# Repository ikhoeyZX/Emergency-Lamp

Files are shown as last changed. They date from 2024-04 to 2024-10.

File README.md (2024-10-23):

# Undens Lampu Emergency

This repository contains the source code for build a Emergency lamp based STM8 or ESP8266.

* Note: ESP8266 version are __not recommended__ but you can build it, but beware it sometimes crash and heating up when using step-up ic / module at low battery level (below 3V)

# Reason?

In my country there is much earthquake, well because i'm life in ring of fire area, i did experience big earthquake back in 2017. When earthquake happen, my family still sleeping (it around 12AM) and got blackout, there is no way to find door or find a place to protect our selfes because it's too dark to see. So that's why i make this in case it happen again we still got light to find exit or place to protect out selfes.

Most commercial emergency lamp in here are bad because cheap battery (only last 1 year and only hold 1.5h every running) and didn't have protection charger!!

# What version i should make?

There is 2 build exist (ESP8266 and STM8, arduino series will added later) for 1 layer recommended use v1.2 and for 2 layers smd build use v1.3

each folder contains how to build it. You need Android IDE to program it (in STM8 case, make sure your username in PC doesn't have "space" otherwise SDCPP will fail to build because this bug not yet fixed from SDCC it self).

* Note : For step-up ic/module you can find by self, depend of budget, because MOSFET output only act as "switch" so you need step-up to make sure it can output high voltage to light a leds (5v are common but waste much power, i recommended use 4.3v output to reduce power usage)
* MOSFET should be withstand around ~4A continues with heatsink, so if you using step-up and output set 4.3v it should be around ~4A Max in input side
* In my case only use 1A at MOSFET output and 4400mA battery. it can run without issue around 4H with 20 leds (~30mA/leds) in 12 places at home.

## Finished device:

| **Main device** | **A Step up ic MT3608** |
| :---: | :---: |
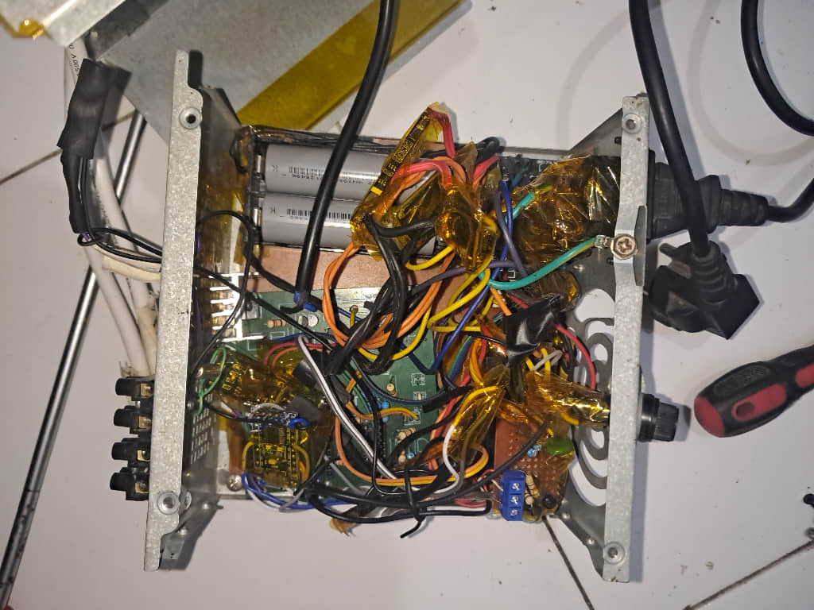
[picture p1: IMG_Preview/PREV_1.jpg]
Main device
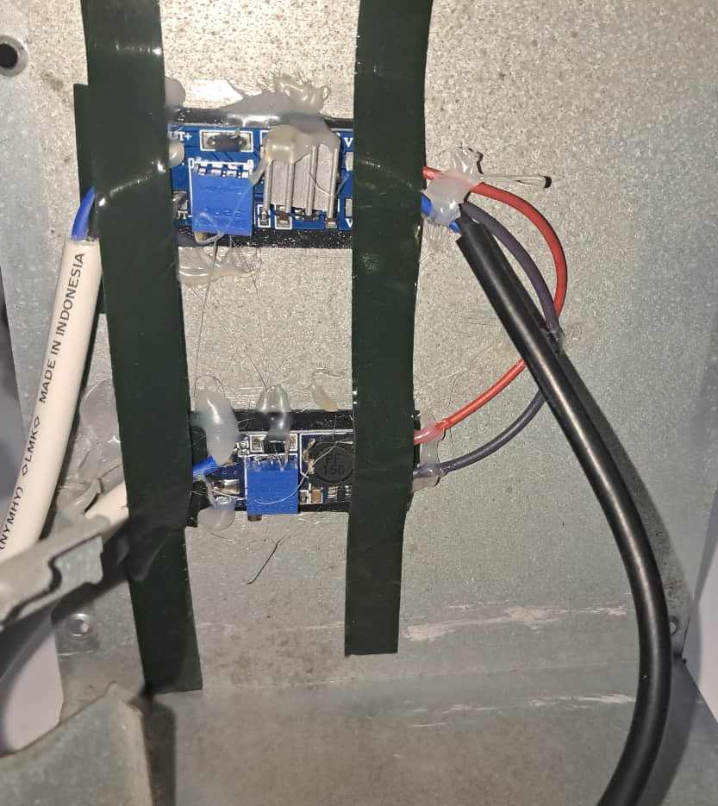
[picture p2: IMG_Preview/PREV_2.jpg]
Step up ic
|  |  |

| **Main device when running** | **A led that used, smd led 3v with 5v input (with 47ohm resistor)** |
| :---: | :---: |
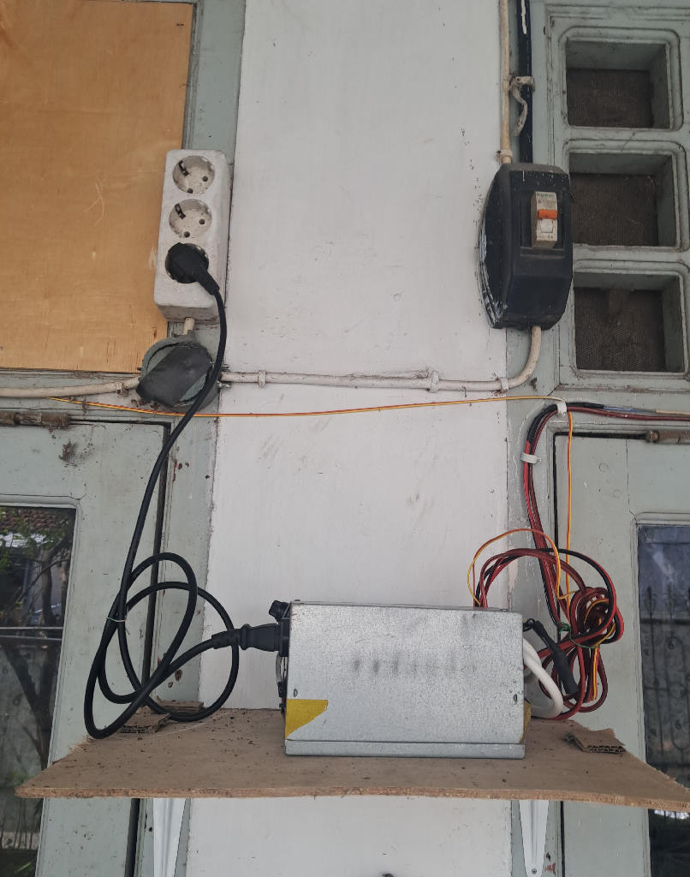
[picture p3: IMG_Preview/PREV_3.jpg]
Main device when running
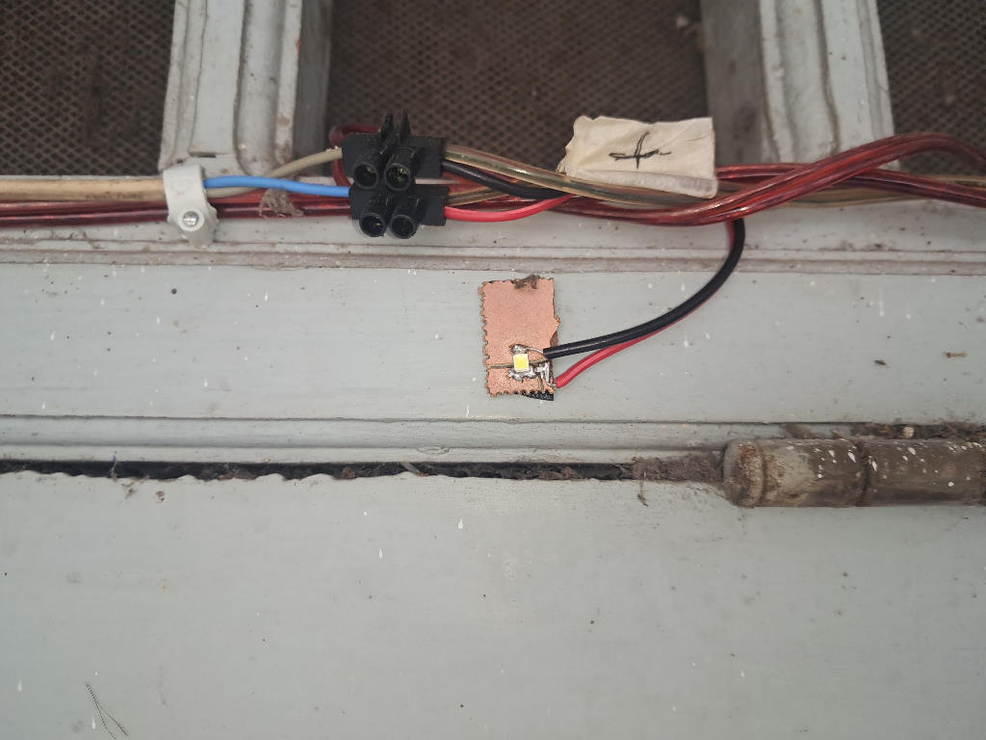
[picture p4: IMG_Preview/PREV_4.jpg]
A led that used for emergency
|  |  |

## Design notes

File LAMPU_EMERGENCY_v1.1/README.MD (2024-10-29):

this module using external battery charger

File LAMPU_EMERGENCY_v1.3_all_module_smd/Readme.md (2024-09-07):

To make this follow "Build.png"

for output you need external step-up, you can use MT3608 / QC 3.0 or other step-up, 5v output is recommended for better battery life

for 2A or higher put heatsink in MOSFET!

for speaker, this build use "buzzer type"

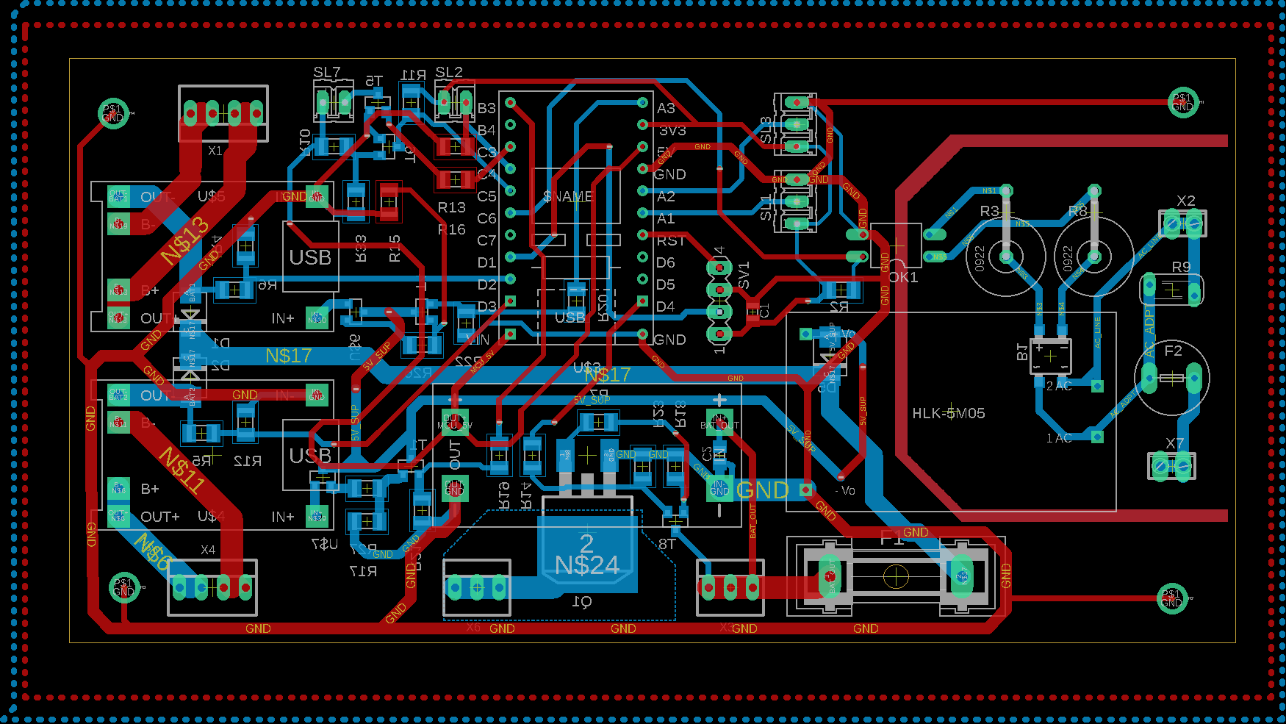
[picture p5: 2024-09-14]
LAMPU_EMERGENCY_v1.3_all_module_smd/ALL.png

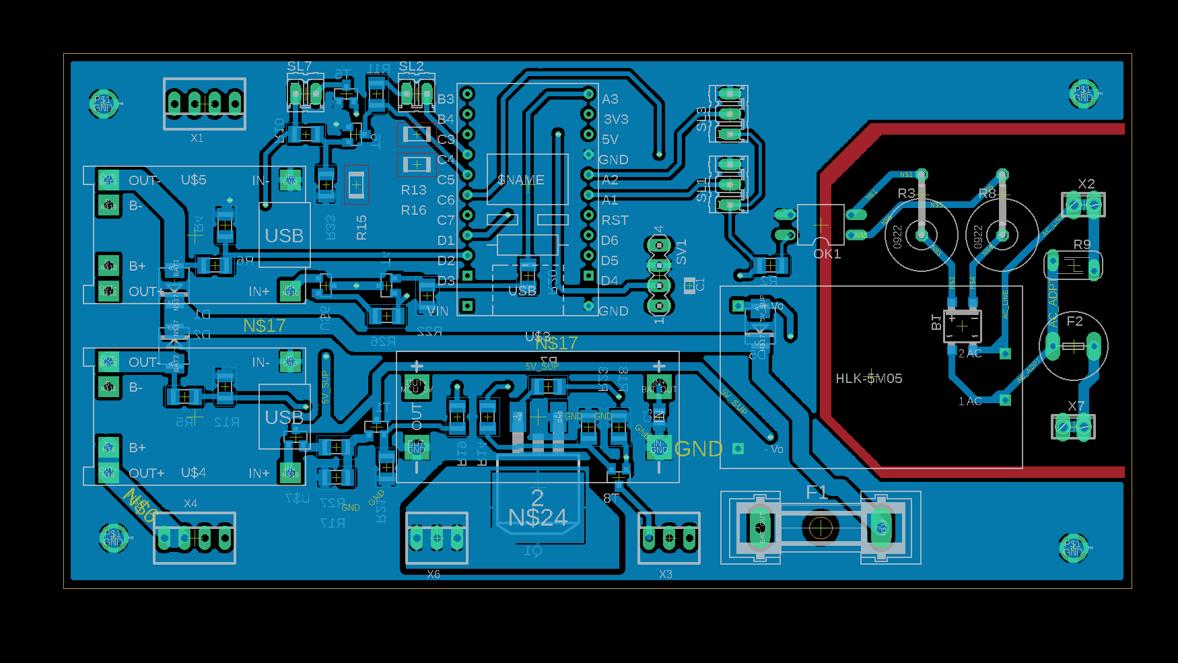
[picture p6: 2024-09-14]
LAMPU_EMERGENCY_v1.3_all_module_smd/BOTTOM.png

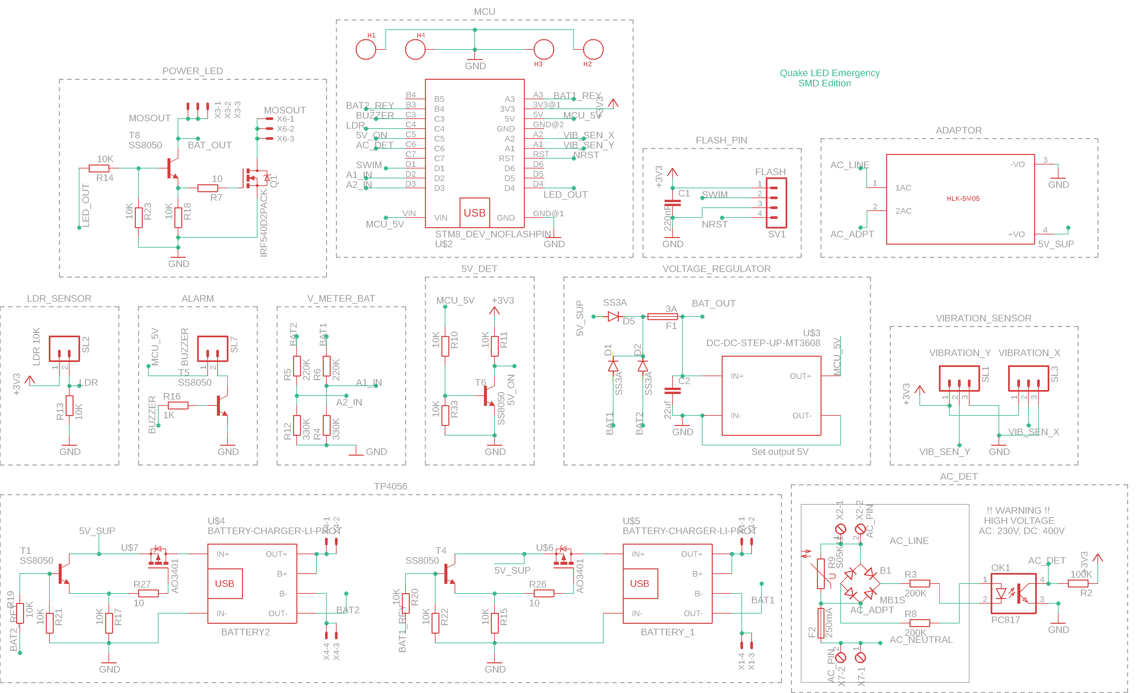
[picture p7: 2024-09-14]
LAMPU_EMERGENCY_v1.3_all_module_smd/SCH.png

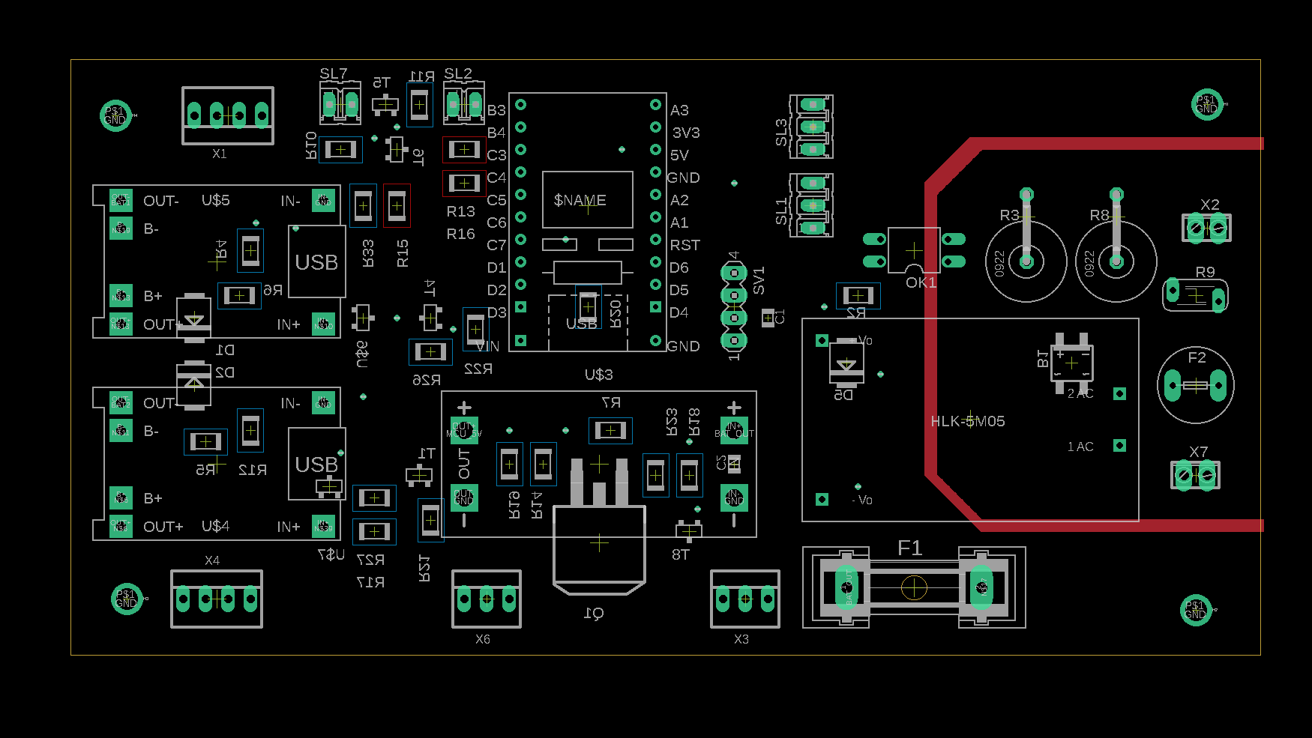
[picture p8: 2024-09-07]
LAMPU_EMERGENCY_v1.3_all_module_smd/PART.png

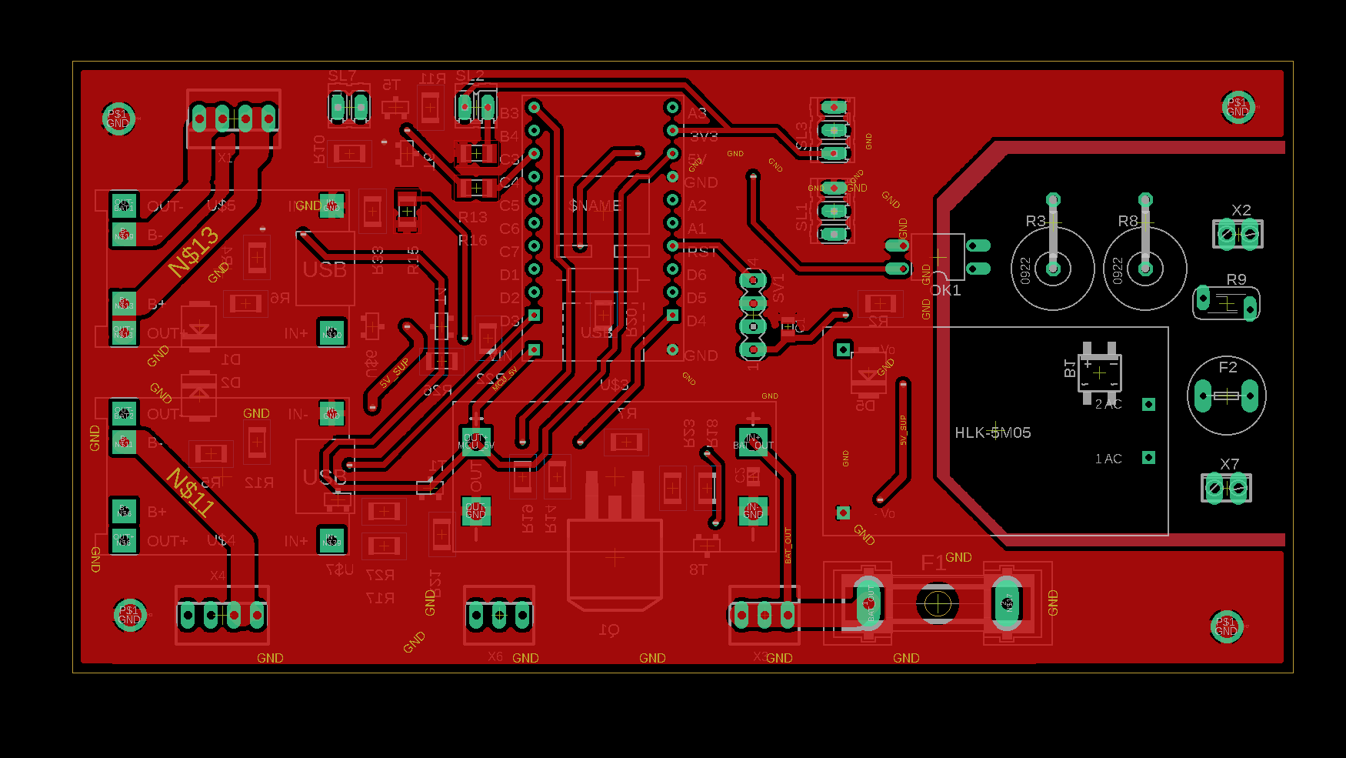
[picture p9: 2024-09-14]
LAMPU_EMERGENCY_v1.3_all_module_smd/TOP.png

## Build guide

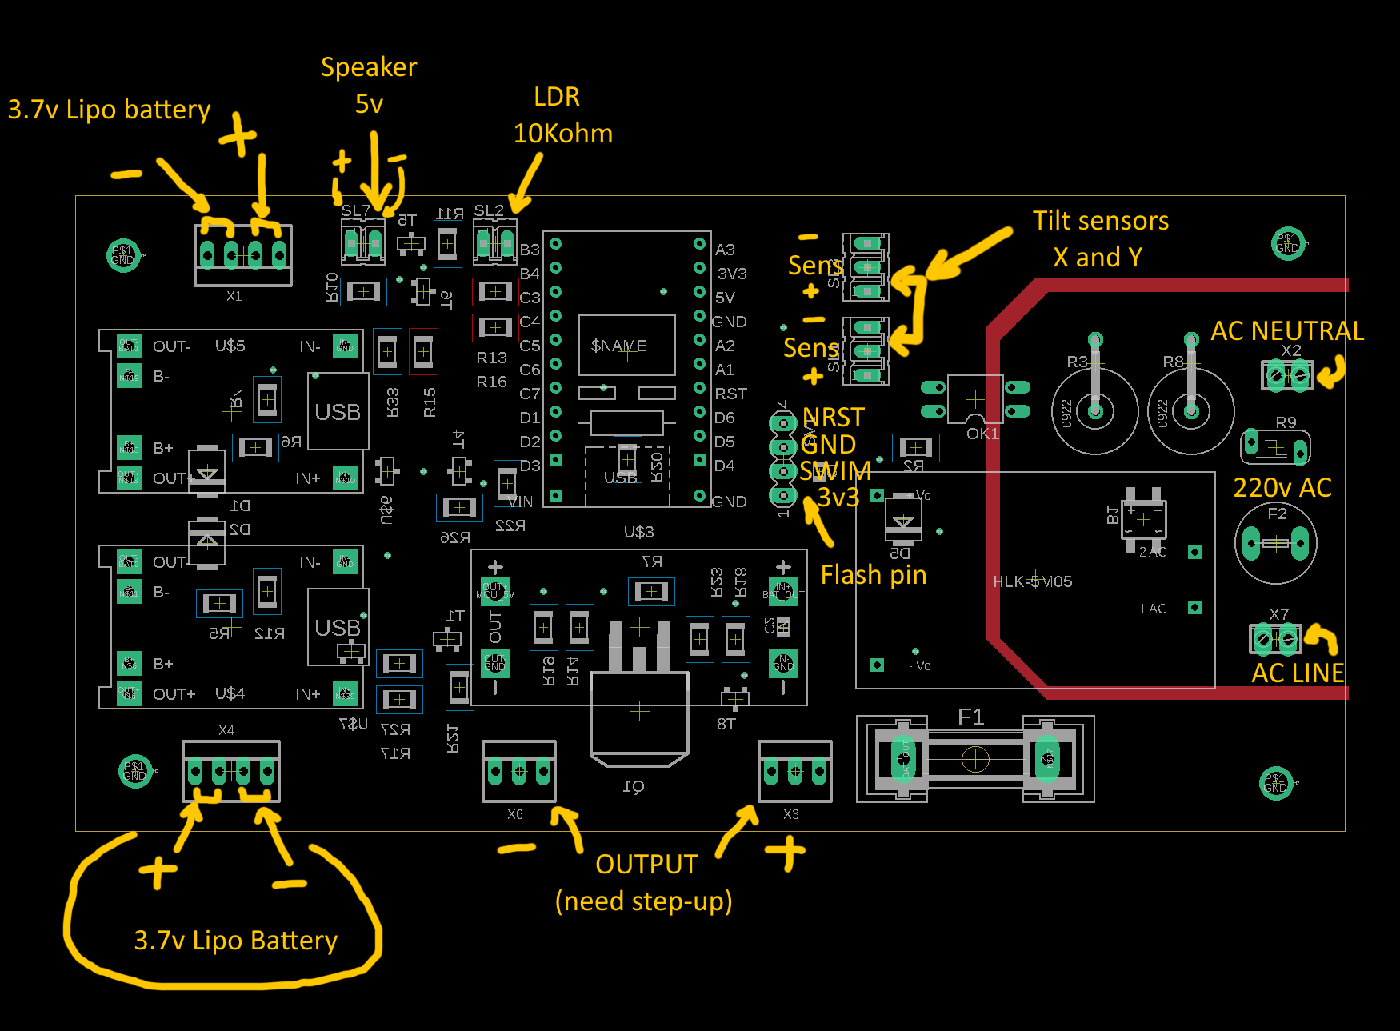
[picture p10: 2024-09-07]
LAMPU_EMERGENCY_v1.3_all_module_smd/BUILD.png

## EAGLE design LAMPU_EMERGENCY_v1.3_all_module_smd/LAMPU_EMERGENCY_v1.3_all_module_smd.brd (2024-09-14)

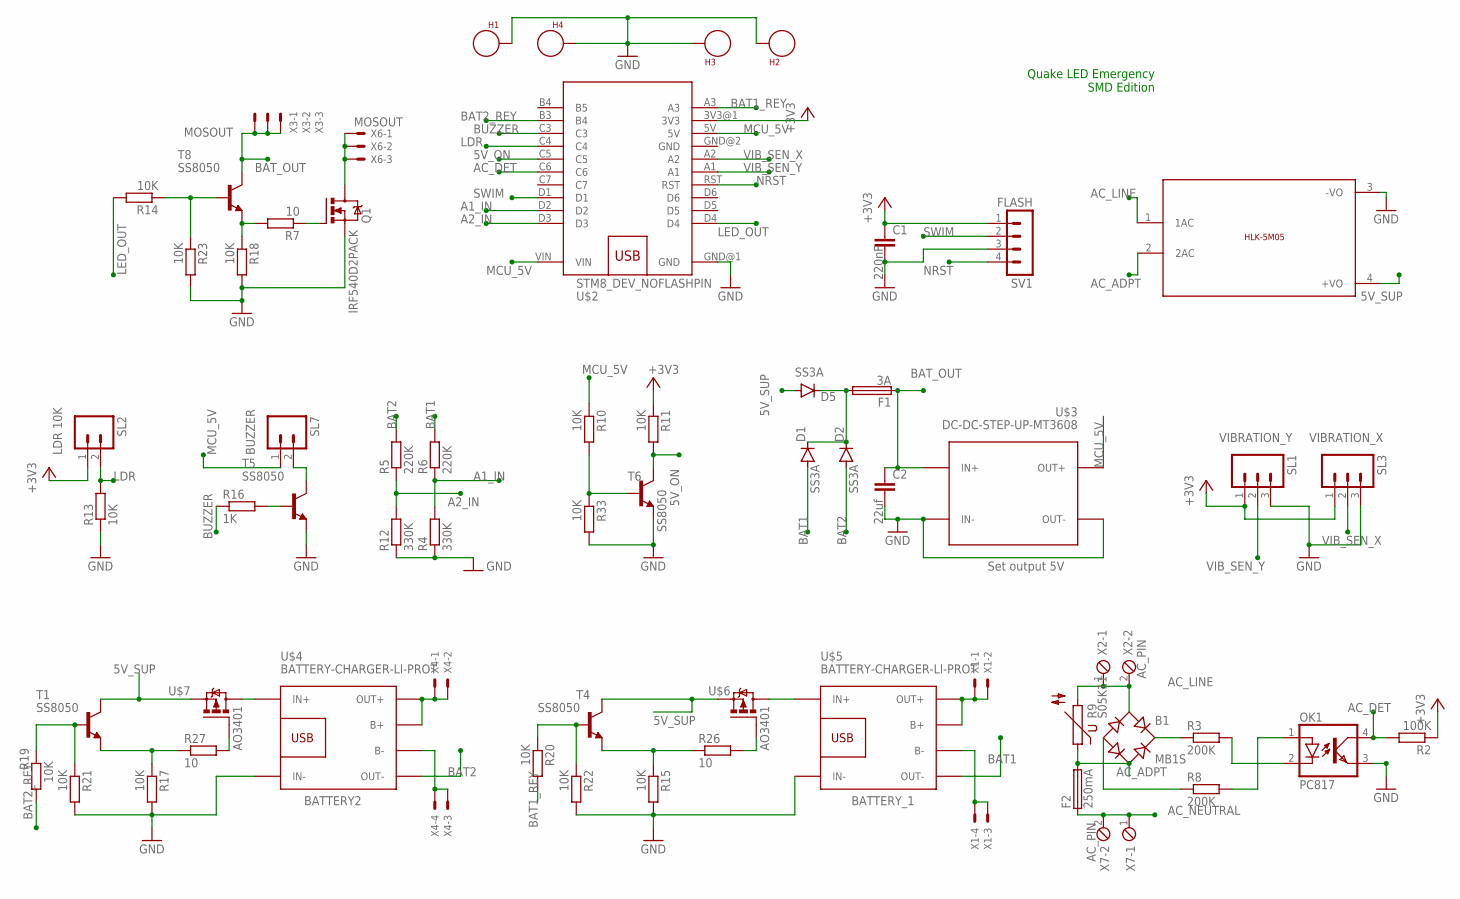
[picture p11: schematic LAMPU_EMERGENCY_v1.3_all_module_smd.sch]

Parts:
B1: MB1S; SOIC-4
C1: 220nF; C0805K
C2: 22uf; C0805K
D1, D2, D5: SS3A; SMB
F1: 3A; GSH15
F2: 250mA; TR5
H1, H2, H3, H4: SEW_HOLE; SIMPLE_HOLE
OK1: PC817; DIL04
Q1: IRF540D2PACK; D2PACK
R2: 100K; M1206
R3, R8: 200K; 0922V
R4, R12: 330K; M1206
R5, R6: 220K; M1206
R7, R26, R27: 10; M1206
R9: S05K11
R10, R11, R13, R14, R15, R17, R18, R19, R20, R21, R22, R23, R33: 10K; M1206
R16: 1K; M1206
SL1: VIBRATION_Y; 03P
SL2: LDR 10K; 02P
SL3: VIBRATION_X; 03P
SL7: BUZZER; 02P
SV1: FLASH; MA04-1
T1, T4, T5, T6, T8: SS8050; SOT23
U$1: 5VDC/5W; HLK-5M05
U$2: STM8_DEV_NOFLASHPIN; NO_FLASH_PIN
U$3: DC-DC-STEP-UP-MT3608
U$4, U$5: BATTERY-CHARGER-LI-PROT
U$6, U$7: AO3401; SOT23
X1: BATTERY_1; 22-23-2041
X2, X7: AC_PIN; 2POL254
X3, X6: MOSOUT; 22-23-2031
X4: BATTERY2; 22-23-2041

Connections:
5V_ON: R11.2, T6.3 (C), U$2.C5
5V_SUP: D5.A, T1.3 (C), T4.3 (C), U$1.4 (+VO), U$6.3 (S), U$7.3 (S)
+3V3: C1.1, R2.1, R11.1, SL1.1, SL2.1, SL3.1, SV1.1, U$2.3V3@1 (3V3)
A1_IN: R4.2, R6.1, U$2.D2
A2_IN: R5.1, R12.2, U$2.D3
AC_ADPT: B1.~2 (AC2), F2.2, R9.1, U$1.2 (2AC)
AC_DET: OK1.4 (COL), R2.2, U$2.C6
AC_LINE: B1.~1 (AC1), R9.2, U$1.1 (1AC), X2.1, X2.2
AC_NEUTRAL: F2.1, X7.1, X7.2
BAT1: D1.A, R6.2, U$5.OUT-
BAT1_REY: R20.2, U$2.A3
BAT2: D2.A, R5.2, U$4.OUT-
BAT2_REY: R19.1, U$2.B3 (B4)
BAT_OUT: C2.1, F1.1, T8.3 (C), U$3.IN+, X3.1, X3.2, X3.3
BUZZER: R16.1, U$2.C3
GND: C1.2, C2.2, H1.P$1, H2.P$1, H3.P$1, H4.P$1, OK1.3 (EMIT), Q1.3 (S), R4.1, R12.1, R13.1, R15.2, R17.2, R18.2, R21.2, R22.2, R23.2, R33.2, SL1.3, SL3.3, SV1.3, T5.2 (E), T6.2 (E), U$1.3 (-VO), U$2.GND@1 (GND), U$2.GND@2 (GND), U$3.IN-, U$3.OUT-, U$4.IN-, U$5.IN-
LDR: R13.2, SL2.2, U$2.C4
LED_OUT: R14.2, U$2.D4
MCU_5V: R10.1, SL7.1, U$2.5V, U$2.VIN, U$3.OUT+
unnamed: OK1.2 (C), R3.2
unnamed: R10.2, R33.1, T6.1 (B)
unnamed: B1.+, R3.1
unnamed: B1.-, R8.1
unnamed: OK1.1 (A), R8.2
unnamed: U$4.B+, U$4.OUT+, X4.1, X4.2
unnamed: Q1.1 (G), R7.1
unnamed: R26.2, U$6.1 (G)
unnamed: U$5.IN+, U$6.2 (D)
unnamed: U$4.B-, X4.3, X4.4
unnamed: U$5.B+, U$5.OUT+, X1.1, X1.2
unnamed: R15.1, R26.1, T4.2 (E)
unnamed: SL7.2, T5.3 (C)
unnamed: R27.2, U$7.1 (G)
unnamed: D1.C, D2.C, D5.C, F1.2
unnamed: R16.2, T5.1 (B)
unnamed: U$5.B-, X1.3, X1.4
unnamed: R19.2, R21.1, T1.1 (B)
unnamed: R7.2, R18.1, T8.2 (E)
unnamed: R14.1, R23.1, T8.1 (B)
unnamed: Q1.2 (D), X6.1, X6.2, X6.3
unnamed: R17.1, R27.1, T1.2 (E)
unnamed: R20.1, R22.1, T4.1 (B)
unnamed: U$4.IN+, U$7.2 (D)
NRST: SV1.4, U$2.RST
SWIM: SV1.2, U$2.D1
VIB_SEN_X: SL3.2, U$2.A2
VIB_SEN_Y: SL1.2, U$2.A1

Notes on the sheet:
Quake LED Emergency SMD Edition
Set output 5V

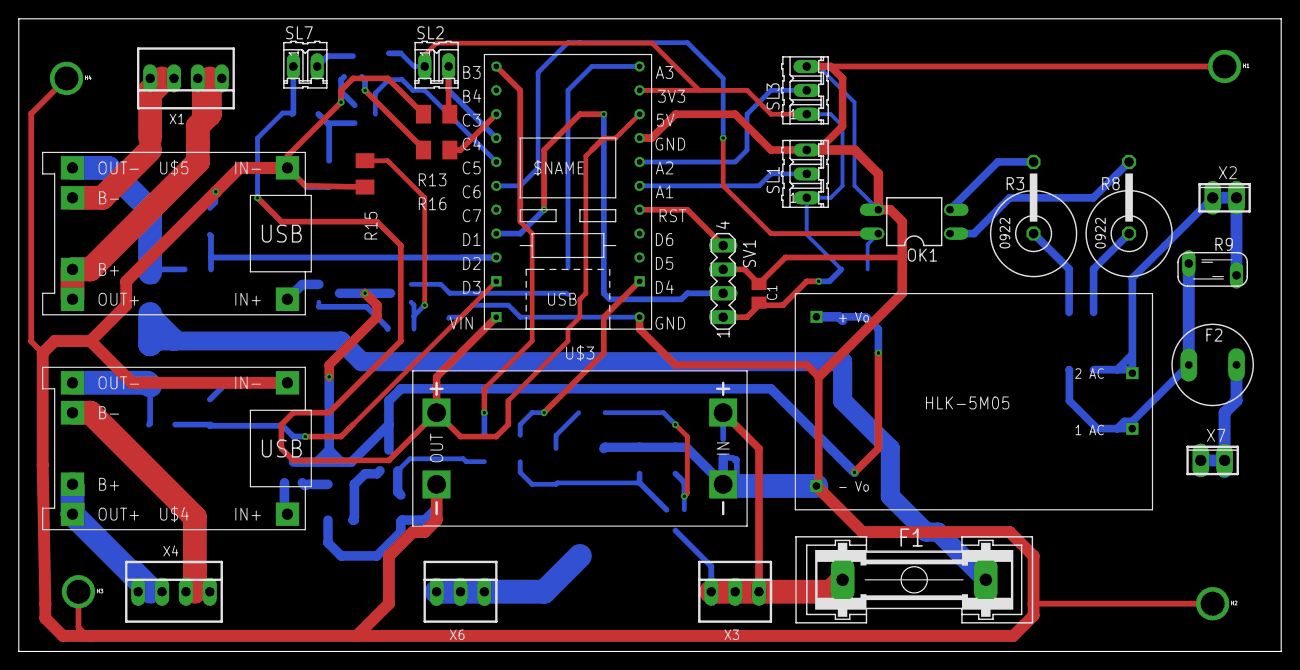
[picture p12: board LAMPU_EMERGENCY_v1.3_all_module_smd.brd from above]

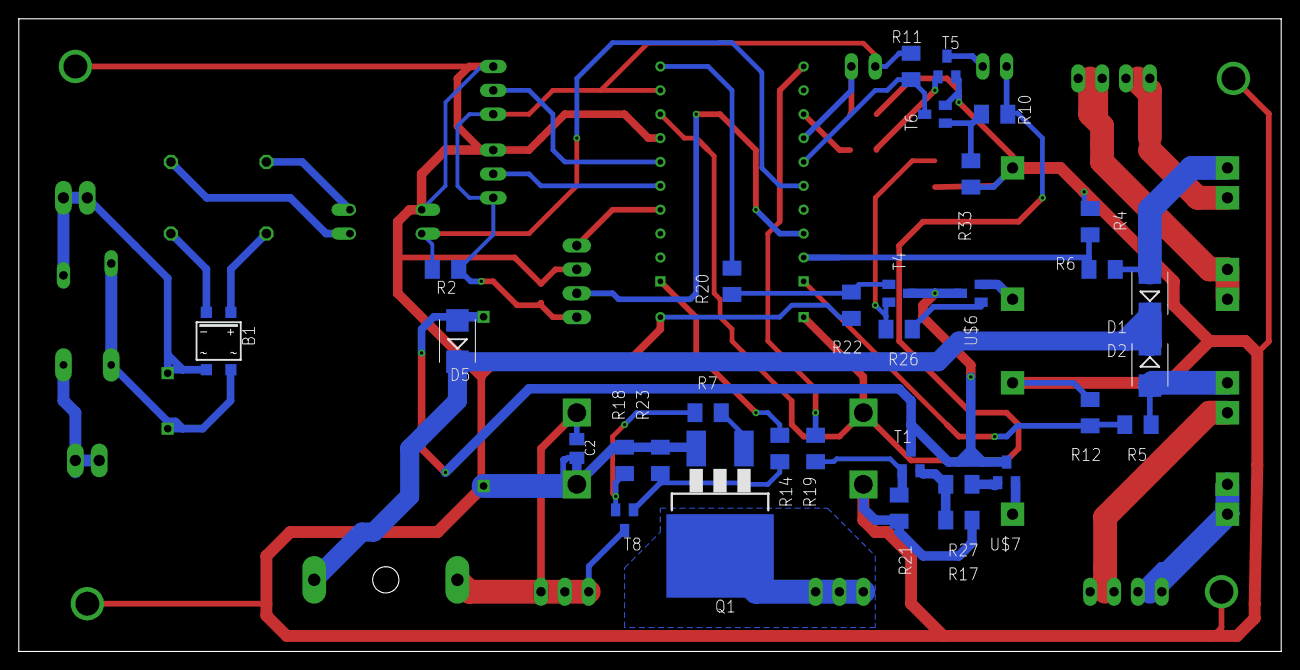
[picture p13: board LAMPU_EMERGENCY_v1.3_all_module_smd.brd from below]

Board: 2 copper layers, 134.3 x 67.3 mm, 62 parts (32 on the bottom side), 47 nets.

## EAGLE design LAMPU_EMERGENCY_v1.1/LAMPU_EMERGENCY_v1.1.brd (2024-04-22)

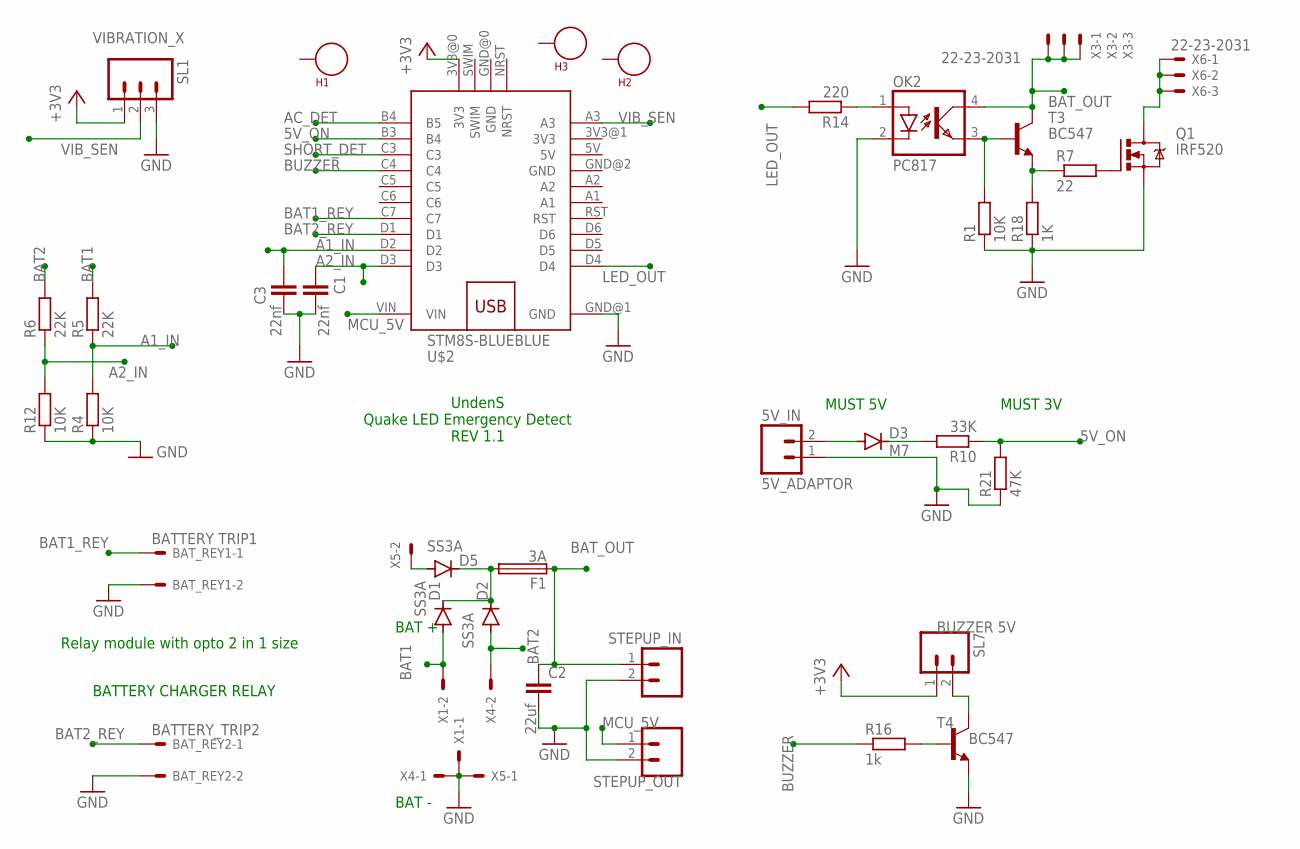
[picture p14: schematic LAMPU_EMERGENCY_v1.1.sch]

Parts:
5V_IN: 5V_ADAPTOR; 02P
BAT_REY1: BATTERY TRIP1; 22-23-2021
BAT_REY2: BATTERY_TRIP2; 22-23-2021
C1, C3: 22nf; C0805K
C2: 22uf; C0805K
D1, D2, D5: SS3A; SMB
D3: M7; SMB
F1: 3A; GSH15
H1, H2, H3: SEW_HOLE; SIMPLE_HOLE
OK2: PC817; DIL04
Q1: IRF520; TO220BV
R1, R4, R12: 10K; 0207/7
R5, R6: 22K; 0207/7
R7: 22; 0207/7
R10: 33K; 0207/7
R14: 220; 0207/7
R16: 1k; 0207/7
R18: 1K; 0207/7
R21: 47K; 0207/7
SL1: VIBRATION_X; 03P
SL7: BUZZER 5V; 02P
STEP_IN: STEPUP_IN; 02P
STEP_MCU: STEPUP_OUT; 02P
T3, T4: BC547; TO92
U$2: STM8S-BLUEBLUE; WEMOS-D1-MINI
X1, X4, X5: 22-23-2021
X3, X6: 22-23-2031

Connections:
3V3: U$2.3V3@1 (3V3)
5V: U$2.5V
5V_ON: R10.1, R21.2, U$2.B3 (B4)
+3V3: SL1.1, SL7.1, U$2.3V3@0 (3V3)
A1_IN: C3.1, R4.2, R5.1, U$2.D2
A2_IN: C1.1, R6.1, R12.2, U$2.D3
AC_DET: U$2.B4 (B5)
BAT1: D1.A, R5.2, X1.2
BAT1_REY: BAT_REY1.1, U$2.C7
BAT2: D2.A, R6.2, X4.2
BAT2_REY: BAT_REY2.1, U$2.D1
BAT_OUT: C2.1, F1.1, OK2.4 (COL), STEP_IN.1, T3.3 (C), X3.1, X3.2, X3.3
BUZZER: R16.1, U$2.C4
GND: 5V_IN.1, BAT_REY1.2, BAT_REY2.2, C1.2, C2.2, C3.2, OK2.2 (C), Q1.S, R1.1, R4.1, R12.1, R18.1, R21.1, SL1.3, STEP_IN.2, STEP_MCU.2, T4.1 (E), U$2.GND@1 (GND), U$2.GND@2 (GND), X1.1, X4.1, X5.1
LED_OUT: R14.2, U$2.D4
MCU_5V: STEP_MCU.1, U$2.VIN
unnamed: OK2.3 (EMIT), R1.2, T3.2 (B)
unnamed: 5V_IN.2, D3.A
unnamed: SL7.2, T4.3 (C)
unnamed: D1.C, D2.C, D5.C, F1.2
unnamed: R16.2, T4.2 (B)
unnamed: R7.1, R18.2, T3.1 (E)
unnamed: Q1.G, R7.2
unnamed: OK2.1 (A), R14.1
unnamed: Q1.D, X6.1, X6.2, X6.3
unnamed: D3.C, R10.2
unnamed: D5.A, X5.2
SHORT_DET: U$2.C3
VIB_SEN: SL1.2, U$2.A3

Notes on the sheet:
BAT +
BAT -
BATTERY CHARGER RELAY
Relay module with opto 2 in 1 size
MUST 3V
MUST 5V
UndenS Quake LED Emergency Detect REV 1.1

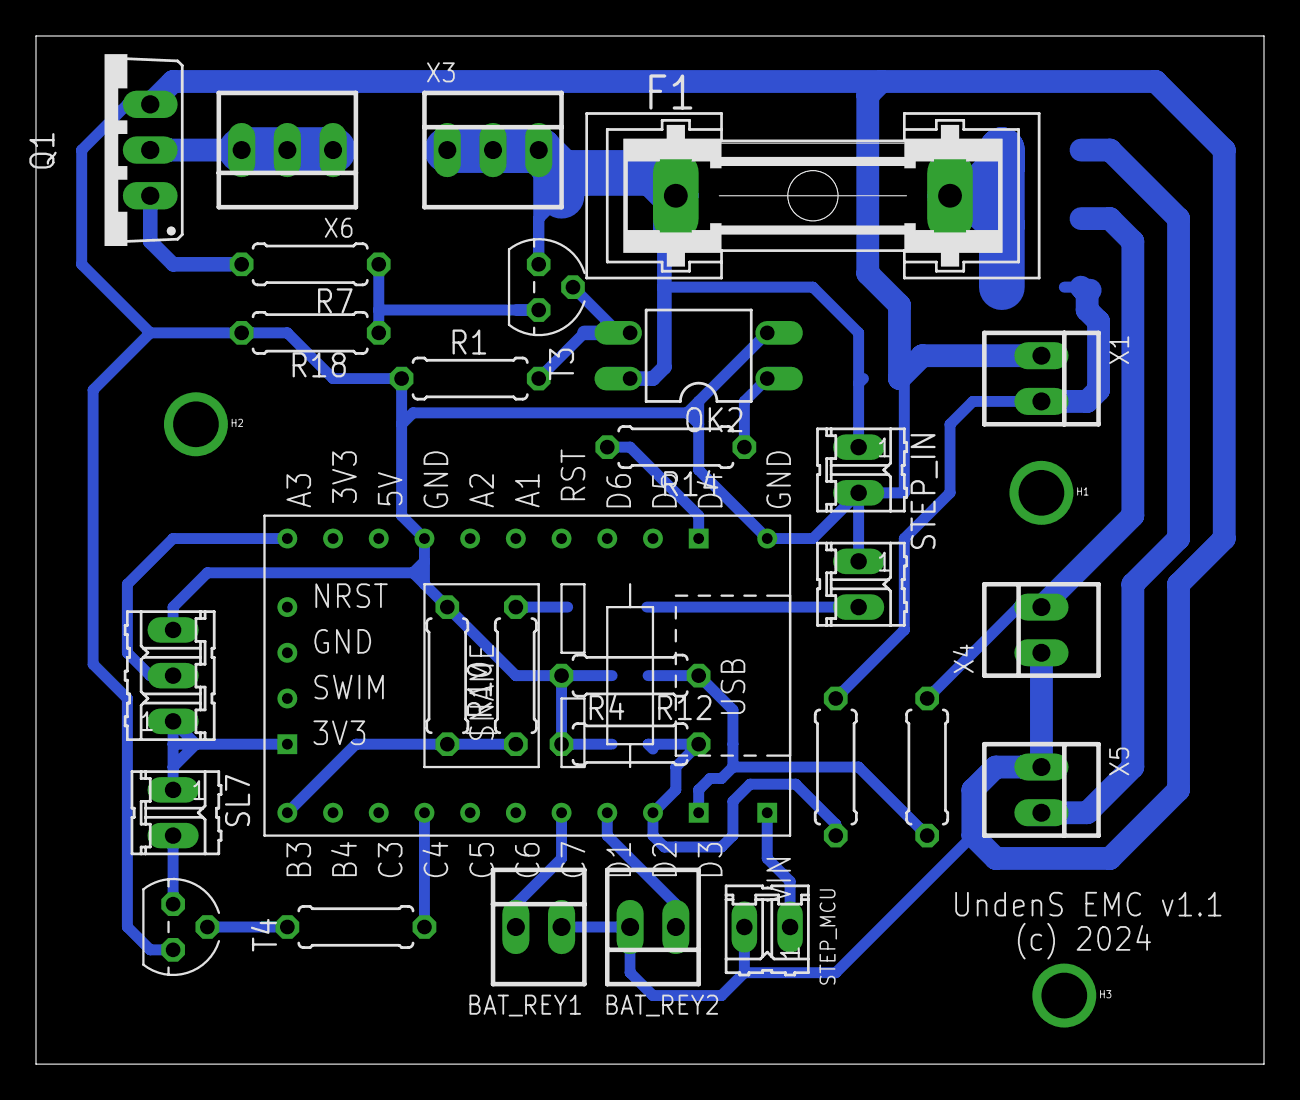
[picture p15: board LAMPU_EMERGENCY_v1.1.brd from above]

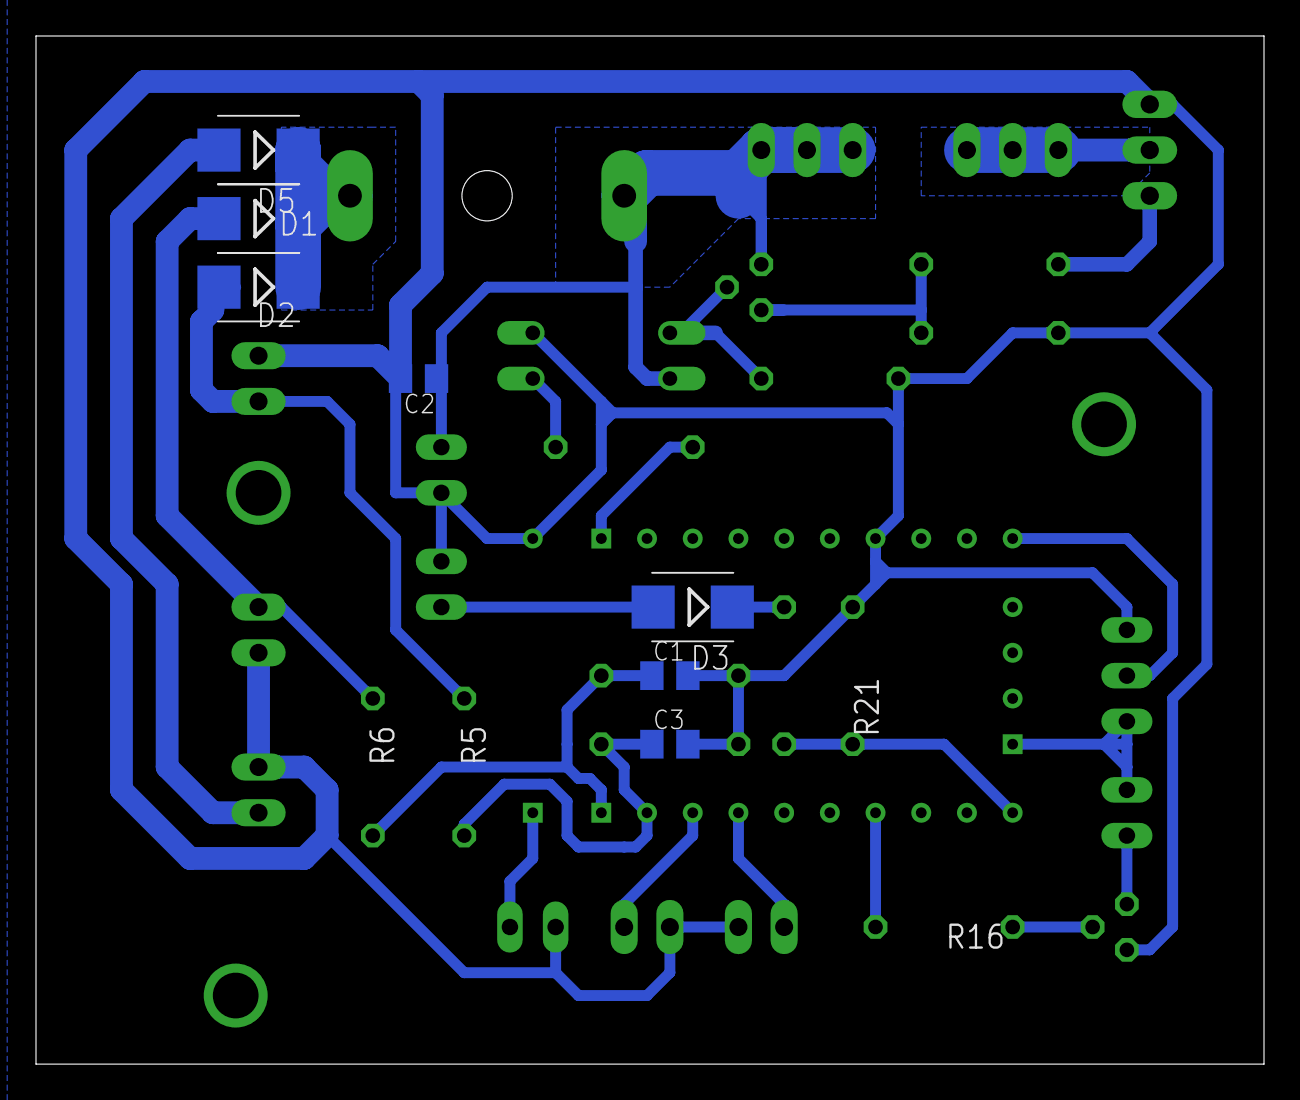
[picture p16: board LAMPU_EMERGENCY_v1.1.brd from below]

Board: 2 copper layers, 68.2 x 57.1 mm, 39 parts (7 on the bottom side), 25 nets.

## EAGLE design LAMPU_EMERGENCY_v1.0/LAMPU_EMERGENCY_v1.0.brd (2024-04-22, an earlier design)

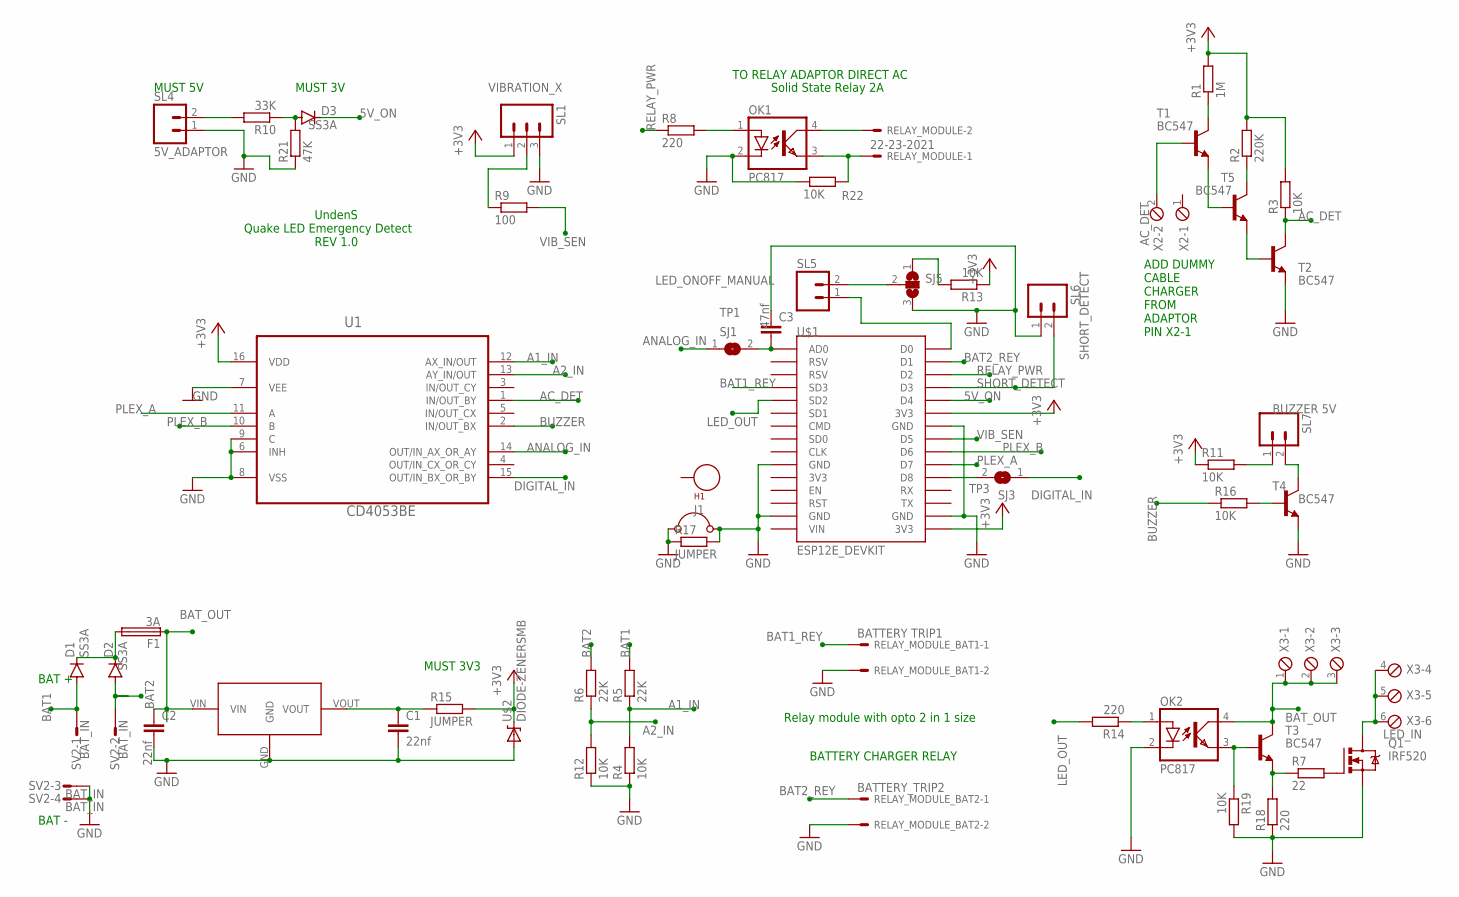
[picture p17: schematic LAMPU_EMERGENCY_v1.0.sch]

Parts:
C1, C2: 22nf; C0805K
C3: 47nf; C0805K
D1, D2, D3: SS3A; SMB
F1: 3A; GSH15
H1: SEW_HOLE; SIMPLE_HOLE
J1: JUMPER; 05
OK1, OK2: PC817; DIL04
Q1: IRF520; TO220BV
R1: 1M; 0207/7
R2: 220K; 0207/7
R3, R4, R11, R12, R13, R16, R19, R22: 10K; 0207/7
R5, R6: 22K; 0207/7
R7: 22; 0207/7
R8, R14, R18: 220; 0207/7
R9: 100; 0207/7
R10: 33K; 0207/7
R15: JUMPER; 0207/15
R17: JUMPER; 0207/7
R21: 47K; 0207/7
RELAY_MODULE: 22-23-2021
RELAY_MODULE_BAT1: BATTERY TRIP1; 22-23-2021
RELAY_MODULE_BAT2: BATTERY_TRIP2; 22-23-2021
SJ1: TP1; SJW
SJ3: TP3; SJW
SJ5: SJ2WW; SJ_2W
SL1: VIBRATION_X; 03P
SL4: 5V_ADAPTOR; 02P
SL5: LED_ONOFF_MANUAL; 02P
SL6: SHORT_DETECT; 02P
SL7: BUZZER 5V; 02P
SV2: BAT_IN; S04P
T1, T2, T3, T4, T5: BC547; TO92
U1: CD4053BE; DIP254P762X508-16
U$1: ESP12E_DEVKIT
U$2: DIODE-ZENERSMB; SMB-DIODE
U$3: HT7333; SOT89
X2: AC_DET; 2POL254
X3: LED_IN; 6POL254

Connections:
5V_ON: D3.C, U$1.D4
+3V3: R1.2, R2.2, R3.2, R11.1, R13.1, R15.2, SL1.1, U1.16 (VDD), U$1.3V3@1 (3V3), U$1.3V3@2 (3V3), U$2.C
A1_IN: R4.2, R5.1, U1.12 (AX_IN/OUT)
A2_IN: R6.1, R12.2, U1.13 (AY_IN/OUT)
AC_DET: R3.1, T2.3 (C), U1.1 (IN/OUT_BY)
ANALOG_IN: SJ1.1, U1.14 (OUT/IN_AX_OR_AY)
BAT1: D1.A, R5.2, SV2.1
BAT1_REY: RELAY_MODULE_BAT1.1, U$1.SD3
BAT2: D2.A, R6.2, SV2.2
BAT2_REY: RELAY_MODULE_BAT2.1, U$1.D1
BAT_OUT: C2.1, F1.1, OK2.4 (COL), T3.3 (C), U$3.VIN, X3.1, X3.2, X3.3
BUZZER: R16.1, U1.2 (IN/OUT_BX)
DIGITAL_IN: SJ3.1, U1.15 (OUT/IN_BX_OR_BY)
GND: C1.2, C2.2, C3.1, J1.1 (+), J1.2 (-), OK1.2 (C), OK2.2 (C), Q1.S, R4.1, R12.1, R17.1, R17.2, R18.1, R19.2, R21.1, R22.1, RELAY_MODULE_BAT1.2, RELAY_MODULE_BAT2.2, SJ5.3, SL1.3, SL4.1, SL6.1, SV2.3, SV2.4, T2.1 (E), T4.1 (E), U1.6 (INH), U1.7 (VEE), U1.8 (VSS), U1.9 (C), U$1.GND@0 (GND), U$1.GND@1 (GND), U$1.GND@2 (GND), U$1.GND@3 (GND), U$2.A, U$3.GND
LED_OUT: R14.2, U$1.SD2
unnamed: SJ3.2, U$1.D8
unnamed: R1.1, T1.3 (C)
unnamed: T1.1 (E), T5.2 (B)
unnamed: R2.1, T5.3 (C)
unnamed: T2.2 (B), T5.1 (E)
unnamed: T1.2 (B), X2.2
unnamed: R13.2, SJ5.1
unnamed: OK1.1 (A), R8.2
unnamed: OK1.4 (COL), RELAY_MODULE.2
unnamed: OK1.3 (EMIT), R22.2, RELAY_MODULE.1
unnamed: C3.2, SJ1.2, U$1.AD0
unnamed: R11.2, SL7.1
unnamed: R9.1, SL1.2
unnamed: SL7.2, T4.3 (C)
unnamed: D3.A, R10.1, R21.2
unnamed: D1.C, D2.C, F1.2
unnamed: R16.2, T4.2 (B)
unnamed: SL5.1, U$1.D0
unnamed: OK2.3 (EMIT), R19.1, T3.2 (B)
unnamed: R7.1, R18.2, T3.1 (E)
unnamed: Q1.G, R7.2
unnamed: OK2.1 (A), R14.1
unnamed: Q1.D, X3.4, X3.5, X3.6
unnamed: R10.2, SL4.2
unnamed: C1.1, R15.1, U$3.VOUT
unnamed: SJ5.2, SL5.2
PLEX_A: U1.11 (A), U$1.D7
PLEX_B: U1.10 (B), U$1.D6
RELAY_PWR: R8.1, U$1.D2
SHORT_DETECT: SL6.2, U$1.D3
VIB_SEN: R9.2, U$1.D5

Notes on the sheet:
MUST 3V3
ADD DUMMY CABLE CHARGER FROM ADAPTOR PIN X2-1
BAT +
BAT -
TO RELAY ADAPTOR DIRECT AC
BATTERY CHARGER RELAY
Solid State Relay 2A
Relay module with opto 2 in 1 size
MUST 3V
MUST 5V
UndenS Quake LED Emergency Detect REV 1.0

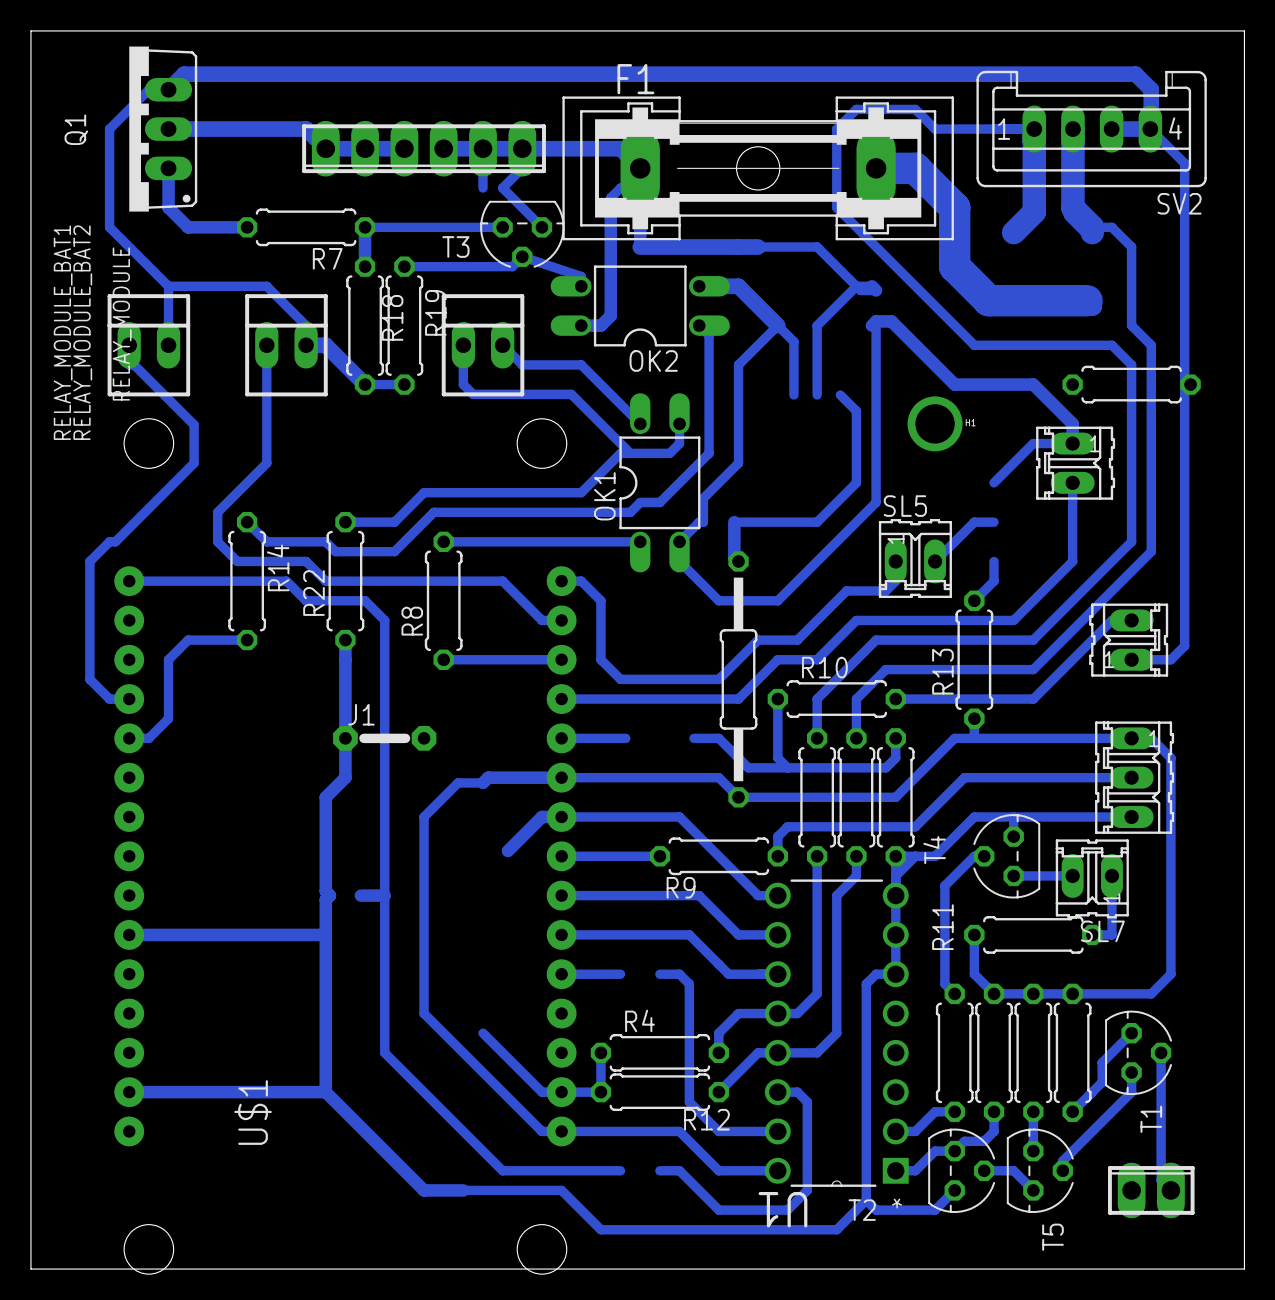
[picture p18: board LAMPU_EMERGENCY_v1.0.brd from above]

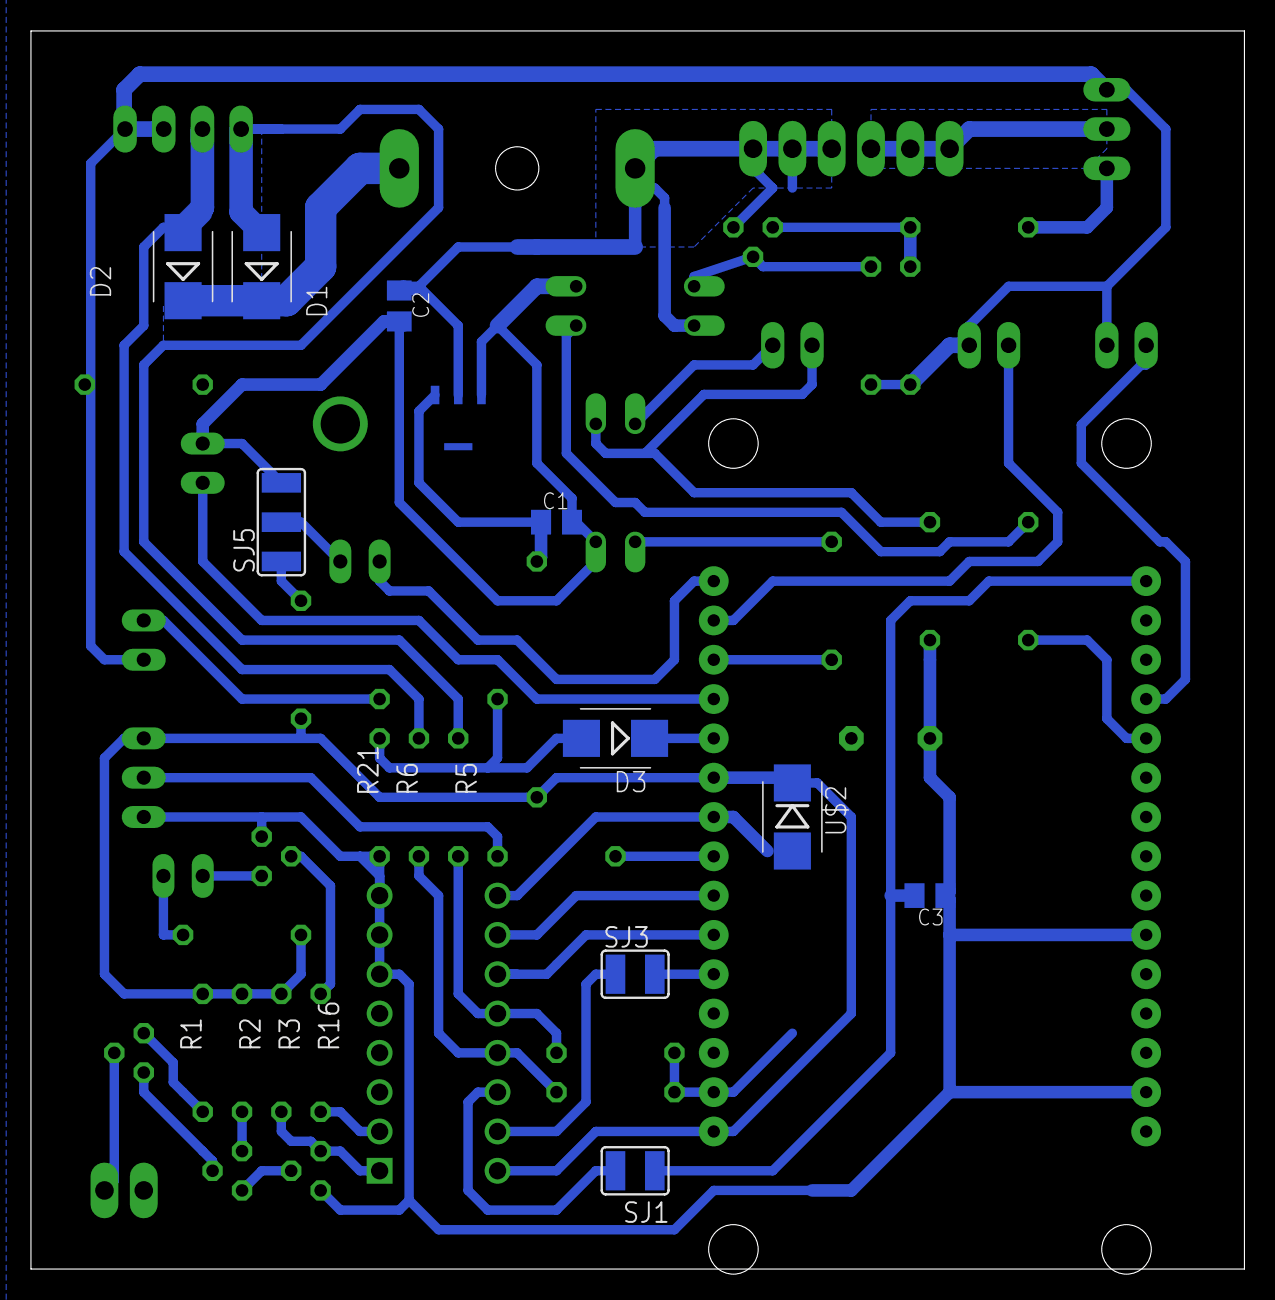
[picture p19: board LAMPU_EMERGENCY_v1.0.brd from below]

Board: 2 copper layers, 78.4 x 80.0 mm, 56 parts (11 on the bottom side), 46 nets.

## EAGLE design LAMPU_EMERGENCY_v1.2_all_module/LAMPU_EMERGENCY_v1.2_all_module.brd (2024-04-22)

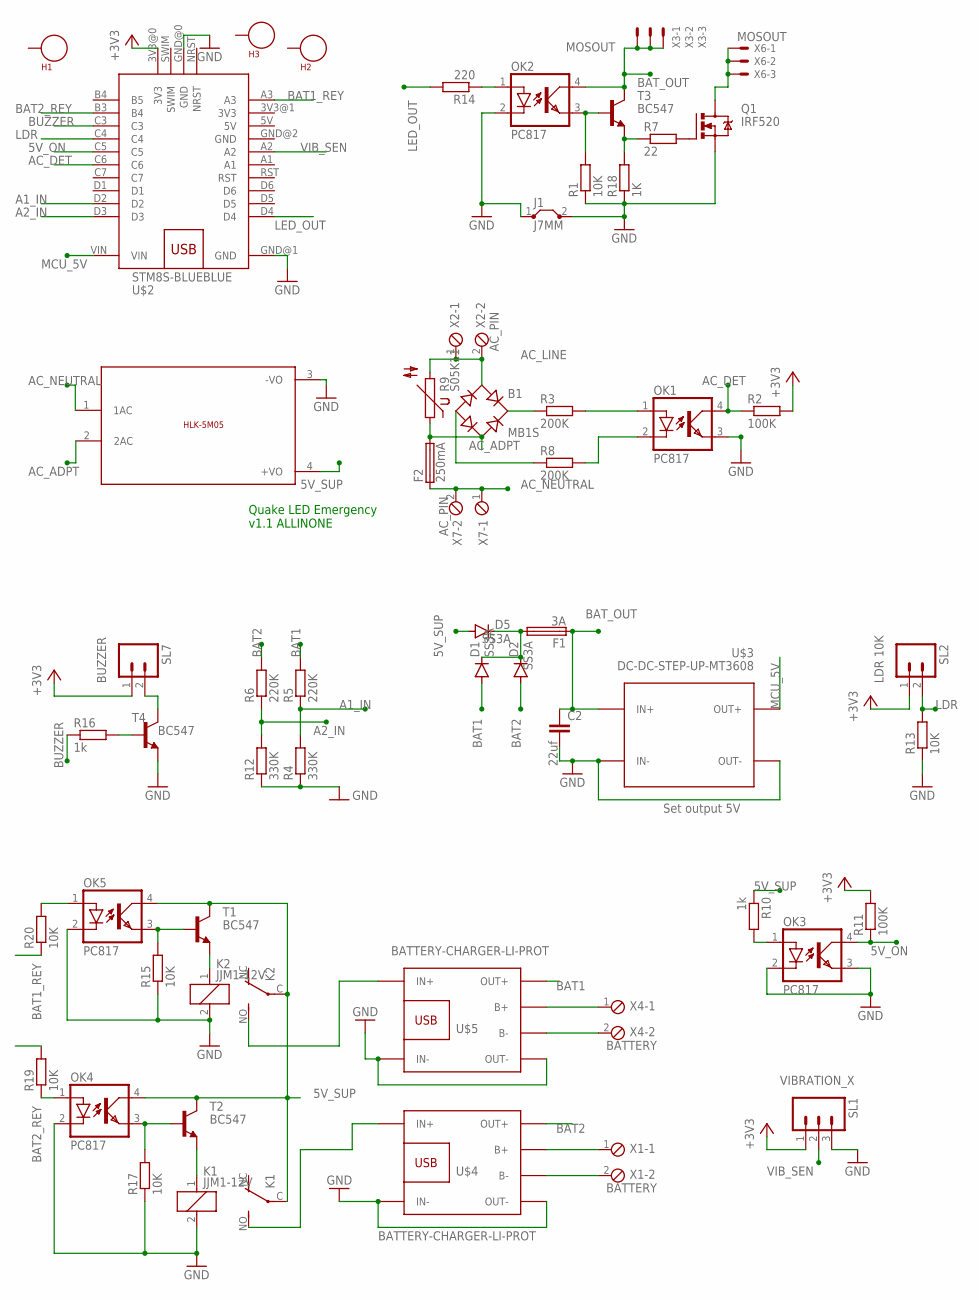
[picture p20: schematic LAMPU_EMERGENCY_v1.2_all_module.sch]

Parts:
B1: MB1S; SOIC-4
C2: 22uf; C0805K
D1, D2, D5: SS3A; SMB
F1: 3A; GSH15
F2: 250mA; TR5
H1, H2, H3: SEW_HOLE; SIMPLE_HOLE
J1: J7MM; 07
K1, K2: JJM1-12V; JJM1C
OK1, OK2, OK3, OK4, OK5: PC817; DIL04
Q1: IRF520; TO220BV
R1, R13, R15, R17, R19, R20: 10K; 0207/7
R2, R11: 100K; 0207/7
R3, R8: 200K; 0922V
R4, R12: 330K; 0207/7
R5, R6: 220K; 0207/7
R7: 22; 0207/7
R9: S05K11
R10, R16: 1k; 0207/7
R14: 220; 0207/7
R18: 1K; 0207/7
SL1: VIBRATION_X; 03P
SL2: LDR 10K; 02P
SL7: BUZZER; 02P
T1, T2, T3, T4: BC547; TO92
U$1: 5VDC/5W; HLK-5M05
U$2: STM8S-BLUEBLUE; WEMOS-D1-MINI
U$3: DC-DC-STEP-UP-MT3608
U$4, U$5: BATTERY-CHARGER-LI-PROT
X1, X4: BATTERY; 2POL254
X2, X7: AC_PIN; 2POL254
X3, X6: MOSOUT; 22-23-2031

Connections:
3V3: U$2.3V3@1 (3V3)
5V: U$2.5V
5V_ON: OK3.4 (COL), R11.1, U$2.C5
5V_SUP: D5.A, K1.C, K2.C, OK4.4 (COL), OK5.4 (COL), R10.1, T1.3 (C), T2.3 (C), U$1.4 (+VO)
+3V3: R2.2, R11.2, SL1.1, SL2.1, SL7.1, U$2.3V3@0 (3V3)
A1_IN: R4.2, R5.1, U$2.D2
A2_IN: R6.1, R12.2, U$2.D3
AC_ADPT: B1.~2 (AC2), F2.2, R9.1, U$1.2 (2AC)
AC_DET: OK1.4 (COL), R2.1, U$2.C6
AC_LINE: B1.~1 (AC1), R9.2, X2.1, X2.2
AC_NEUTRAL: F2.1, U$1.1 (1AC), X7.1, X7.2
BAT1: D1.A, R5.2, U$5.OUT+
BAT1_REY: R20.1, U$2.A3
BAT2: D2.A, R6.2, U$4.OUT+
BAT2_REY: R19.2, U$2.B3 (B4)
BAT_OUT: C2.1, F1.1, OK2.4 (COL), T3.3 (C), U$3.IN+, X3.1, X3.2, X3.3
BUZZER: R16.1, U$2.C3
GND: C2.2, J1.1, J1.2, K1.2, K2.2, OK1.3 (EMIT), OK2.2 (C), OK3.2 (C), OK3.3 (EMIT), OK4.2 (C), OK5.2 (C), Q1.S, R1.1, R4.1, R12.1, R13.1, R15.1, R17.1, R18.1, SL1.3, T4.1 (E), U$1.3 (-VO), U$2.GND@0 (GND), U$2.GND@1 (GND), U$2.GND@2 (GND), U$3.IN-, U$3.OUT-, U$4.IN-, U$4.OUT-, U$5.IN-, U$5.OUT-
LDR: R13.2, SL2.2, U$2.C4
LED_OUT: R14.2, U$2.D4
MCU_5V: U$2.VIN, U$3.OUT+
unnamed: OK2.3 (EMIT), R1.2, T3.2 (B)
unnamed: OK3.1 (A), R10.2
unnamed: B1.+, R3.1
unnamed: B1.-, R8.1
unnamed: OK1.2 (C), R8.2
unnamed: K1.NO (S), U$4.IN+
unnamed: OK1.1 (A), R3.2
unnamed: K2.NO (S), U$5.IN+
unnamed: U$4.B-, X1.2
unnamed: U$4.B+, X1.1
unnamed: U$5.B-, X4.2
unnamed: U$5.B+, X4.1
unnamed: OK5.3 (EMIT), R15.2, T1.2 (B)
unnamed: SL7.2, T4.3 (C)
unnamed: K2.1, T1.1 (E)
unnamed: D1.C, D2.C, D5.C, F1.2
unnamed: R16.2, T4.2 (B)
unnamed: R7.1, R18.2, T3.1 (E)
unnamed: Q1.G, R7.2
unnamed: OK2.1 (A), R14.1
unnamed: Q1.D, X6.1, X6.2, X6.3
unnamed: OK4.3 (EMIT), R17.2, T2.2 (B)
unnamed: K1.1, T2.1 (E)
unnamed: OK5.1 (A), R20.2
unnamed: OK4.1 (A), R19.1
VIB_SEN: SL1.2, U$2.A2

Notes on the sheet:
Quake LED Emergency v1.1 ALLINONE
Set output 5V

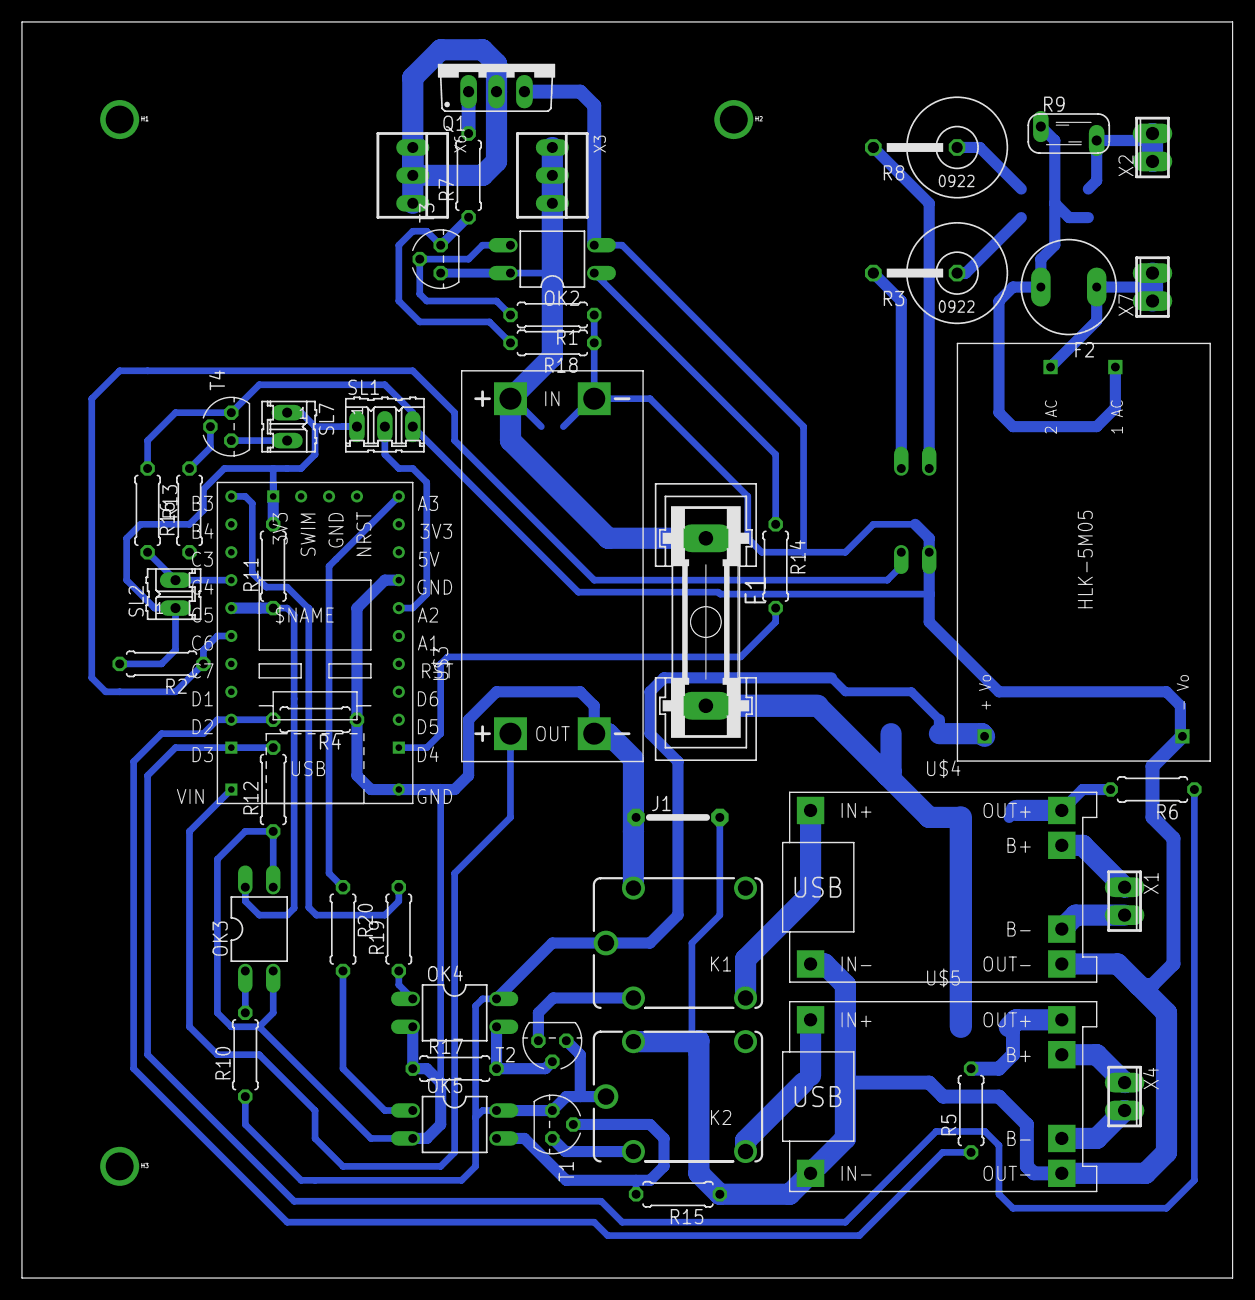
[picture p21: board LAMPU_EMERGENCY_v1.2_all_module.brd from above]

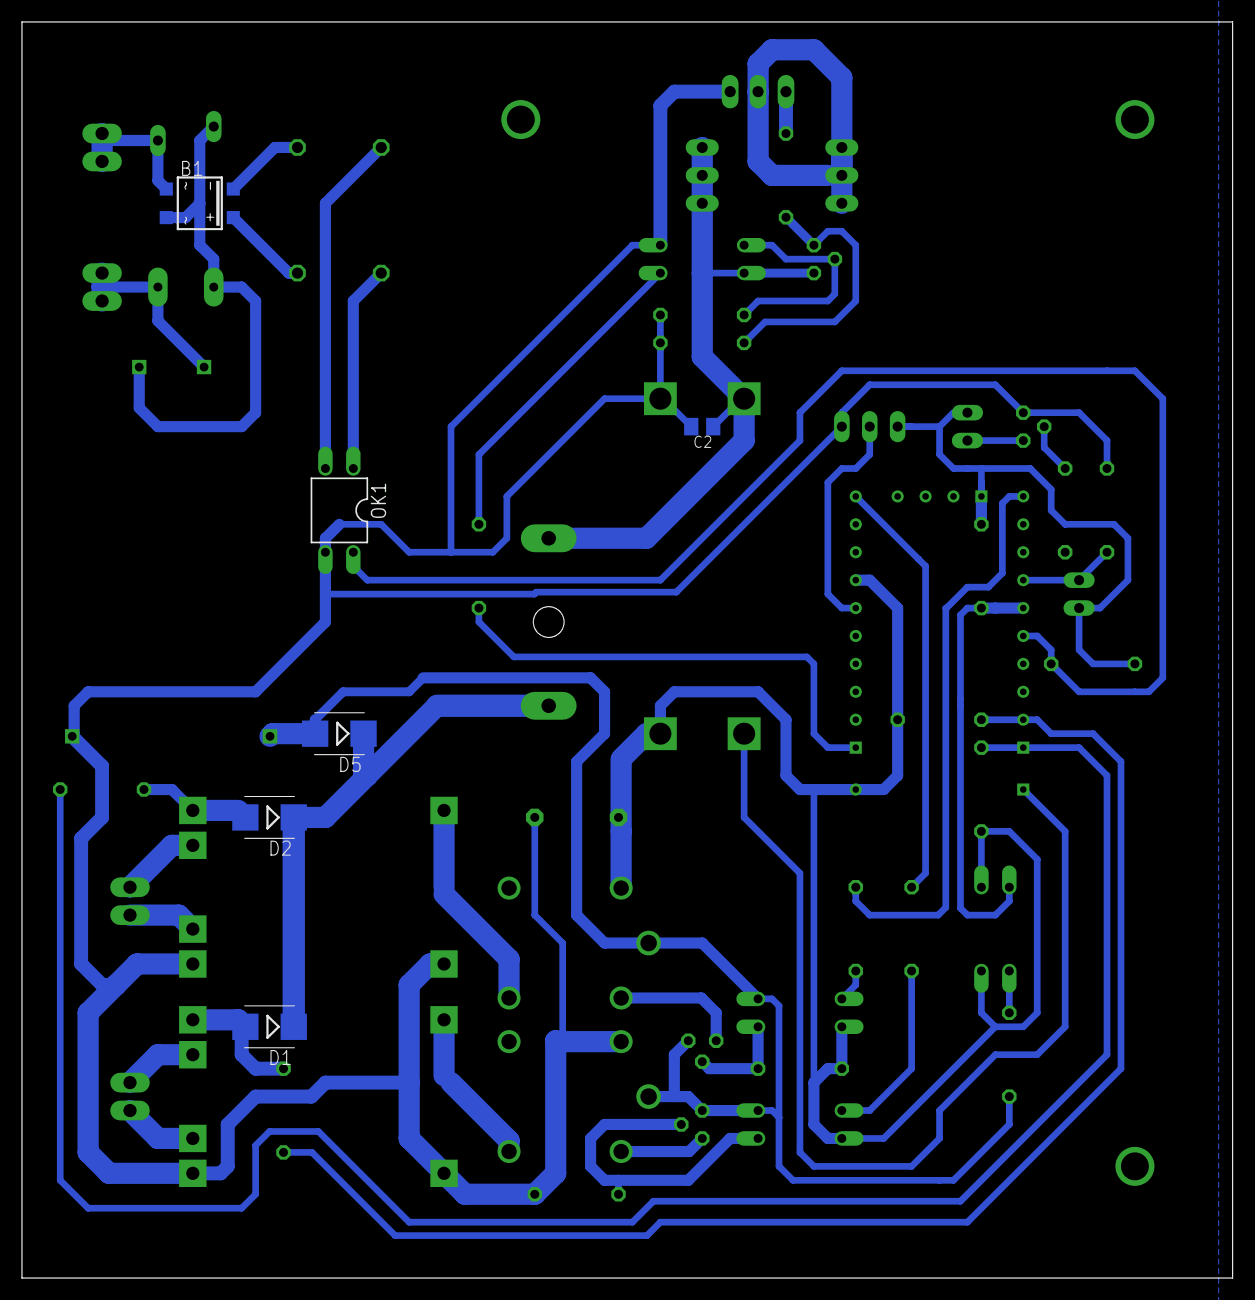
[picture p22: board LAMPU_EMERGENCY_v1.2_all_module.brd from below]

Board: 2 copper layers, 110.2 x 114.3 mm, 57 parts (6 on the bottom side), 45 nets.

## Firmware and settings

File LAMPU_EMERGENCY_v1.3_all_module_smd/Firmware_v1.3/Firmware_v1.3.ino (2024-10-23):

/*********
//
// Lampu Emergency v1.3 REV 0, (c) 2023 - 2024 Undens Corp.
// DESIGNED FOR STM8 SMD board
//
**********/

#include <Serial.h>
#define digitalPinToInterrupt(p)  ((p)==(p)) // workaround-fix, empty macro is missing in header files

/*********
//
// PIN
//
**********/
// DIGITAL
const uint8_t BAT1_REY=2;   // Battery charger 1 mosfet
const uint8_t BAT2_REY=4;   // Battery charger 2 mosfet
const uint8_t BUZZER=5;     // Speaker buzzer type
const uint8_t V5_ON=7;      // Adapt detector
const uint8_t AC_DET=8;     // AC voltage detector
const uint8_t VIB_SEN_X=PA1;  // Vibrator sensor
const uint8_t VIB_SEN_Y=PA2;  // Vibrator sensor
const uint8_t MOSFETOUT=13; // PIN LED_OUT

// ANALOG
const uint8_t LDR=PC4;
const uint8_t BAT1=PD2;
const uint8_t BAT2=PD3;

// VARIABLE
volatile bool quakedet = LOW;
const uint16_t LDRtrig = 200;	// Set LDR detect as no light
const uint16_t limit = 2560; 	// Set limit count to reread battery since no need read battery every milis, max uint16_t is 65535

uint16_t bat1cal = 512;		 // Battery calibration, need DMM to calibrate it
uint16_t bat2cal = 512;		 // Battery calibration, need DMM to calibrate it

float bat1s=0,bat2s = 0;		// Set default battery condition
float battery_full = 4.18;  // battery full
float battery_low = 3.35;   // battery empty

uint16_t count = 0;         // counting to trigger "limit"
bool buzzcall = false;      // time loop buzzer ring

/*********
//
// Speaker
//
**********/
void buzzer(uint16_t duration){  // max 65535ms should be enough
  digitalWrite(BUZZER,HIGH);
  delay(duration);
  digitalWrite(BUZZER,LOW);
  delay(duration/2);
}
 

/*********
//
// Read battery
//
**********/
float baterai(uint8_t pinbat, uint16_t batcal, uint8_t relaypin, bool pilih){  // read battery
  float a=0; 
  for(uint8_t b=0; b<10; b++){    // Smoothing battery value
    a = a + ((analogRead(pinbat) * (3.3 / batcal)));
    delay(1);
  }
  a = a/10;
  
  if(!pilih){ // flipped since P-channel mosfet
    if(a >= battery_full){ // when battery full
      digitalWrite(relaypin, LOW);  
    }else if(a <= 1){  // when no battery
      digitalWrite(relaypin, LOW); 
    }else if(a <= (battery_full - 0.28) && a > 1){  // when battery low
      digitalWrite(relaypin, HIGH);
    }
  }else{ // when battery finished charger
    digitalWrite(relaypin, LOW);
  }

  return a;   // return battery value
}

void ledbuildin(){
  digitalWrite(LED_BUILTIN, LOW);     // turn the LED off (HIGH is the voltage level)
  delay(10);                          // wait for a second
  digitalWrite(LED_BUILTIN, HIGH);    // turn the LED on by making the voltage LOW
  delay(10);   
}

bool smoothlogic(uint16_t sensorin){  // smoothing digital AC detector
  uint8_t acc=0;

  for(uint8_t c=0; c<5; c++){
    acc = acc + digitalRead(sensorin);
    delay(1);
  }
  if(acc >3){   // when AC voltage detected high for 3x
    return HIGH;
  }

  return LOW;
}

void ISR(){ // Interrupt because quake sensor trigger (tilt sensor)
  quakedet = HIGH;
  digitalWrite(BUZZER,HIGH);
}

/*********
//
// Setup
//
**********/
void setup() {
  // DIGITAL PIN
  pinMode(BAT1_REY, OUTPUT);
  pinMode(BAT2_REY, OUTPUT);
  pinMode(BUZZER, OUTPUT);
  pinMode(V5_ON, INPUT_PULLUP);
  pinMode(AC_DET, INPUT_PULLUP);
  pinMode(VIB_SEN_X, INPUT_PULLUP);
  pinMode(VIB_SEN_Y, INPUT_PULLUP);
  pinMode(MOSFETOUT, OUTPUT);
  pinMode(LED_BUILTIN, OUTPUT);

  // ANALOG INPUT PIN: BAT1, BAT2, LDR
  digitalWrite(BAT1_REY,HIGH);
  digitalWrite(BAT2_REY,HIGH);
  digitalWrite(MOSFETOUT,HIGH);

///////////////////////////////////////////////////
// uncomment Serial_begin bellow to calibrate bat1 and bat2 after that you can disable this again
///////////////////////////////////////////////////

  // Serial_begin(9600); 

///////////////////////////////////////////////////

  ledbuildin();
  attachInterrupt(digitalPinToInterrupt(VIB_SEN_X), ISR, CHANGE);
  attachInterrupt(digitalPinToInterrupt(VIB_SEN_Y), ISR, CHANGE);
  buzzer(10);
  buzzer(20);
  buzzer(10);

  // Read battery now!
  bool v5_on = digitalRead(V5_ON);
  bat1s = baterai(BAT1, bat1cal, BAT1_REY, v5_on);
  bat2s = baterai(BAT2, bat2cal, BAT2_REY, v5_on);
}


/*********
//
// Main
//
**********/
void loop() {
  bool v5_on = smoothlogic(V5_ON);
  bool ac = smoothlogic(AC_DET);
  uint16_t bacaldr = analogRead(LDR);

  if(buzzcall){

  }else if(v5_on == HIGH && ac == LOW && !buzzcall){ // ring buzzer if adaptor not yet on but AC voltage exist
    buzzer(50);
    buzzer(5);
    buzzer(20);
    buzzer(10);

    buzzcall = true;
  }

  if(count > limit){
    bat1s = baterai(BAT1, bat1cal, BAT1_REY, v5_on);  // Read battery 1
    bat2s = baterai(BAT2, bat2cal, BAT2_REY, v5_on);  // Read battery 2
    ledbuildin();  // blink led

///////////////////////////////////////////////////
// uncomment bellow this to calibrate battery1 and battery2
///////////////////////////////////////////////////

    // Serial_print_s("\nBat1: ");
    // Serial_println_f(bat1s);
    // Serial_print_s("Bat2: ");
    // Serial_println_f(bat2s);

///////////////////////////////////////////////////
    
    count = 0; //reset counter
    buzzcall = false;
 }else{
    count++;
 }

///////////////////////////////////////////////////
// uncomment bellow this to debug sensors pin output
///////////////////////////////////////////////////

    // Serial_print_s("D5v: ");
    // Serial_println_i(v5_on);
    // Serial_print_s("DAC: ");
    // Serial_println_i(ac);
    // Serial_print_s("SGMP: ");
    // Serial_println_i(quakedet);
    // Serial_print_s("SLDR: ");
    // Serial_println_u(bacaldr);

///////////////////////////////////////////////////


  if(quakedet == HIGH && bacaldr < LDRtrig ){   // Quake detected and it happen at night
    digitalWrite(MOSFETOUT, HIGH);
    ledbuildin();
//    Serial_println_s("GMP_MLM");
    delay(500);
    quakedet= LOW;
  }else if(quakedet== HIGH){  // Quake detected and it happen at morning or afternoon
    digitalWrite(MOSFETOUT, LOW);
    ledbuildin();
//    Serial_println_s("GMP_SNG");
    quakedet = LOW;
  }
  digitalWrite(BUZZER,LOW); // Turn off buzzer after detect quake


  if(!buzzcall){

  }else if(bat1s <= battery_low && bat2s <= battery_low && ac == HIGH){ // Turn off mosfet output because low battery
    digitalWrite(MOSFETOUT, LOW);
//    Serial_println_s("LWBAT");
    delay(10000);
  }else if(bat1s < (battery_low + 0.2) && bat2s <= (battery_low + 0.2) && ac == HIGH && !buzzcall){ // Turn off mosfet output and ring speaker because low battery
    digitalWrite(MOSFETOUT, HIGH);
//    Serial_println_s("LWBAT_WRN");
    buzzer(110);
    buzzer(80);
    buzzer(110);
    buzzcall = true;
  }else if(ac == HIGH && bacaldr < LDRtrig){  // Turn on mosfet because no AC voltage detected
    digitalWrite(MOSFETOUT, HIGH);
//    Serial_println_s("NOACMLM"); 
  }else if(bat1s < 1 && bat2s < 1){   // Turn off mosfet output and ring speaker because battery not detected
    digitalWrite(MOSFETOUT, LOW);
    buzzer(20);
    buzzer(60);
    buzzer(20);
//    Serial_println_s("NOBAT");
    delay(2000);
  }else{      // Turn off mosfet output since no quake and ac voltage detected
//    Serial_println_s("MOSOFF");
    digitalWrite(MOSFETOUT, LOW);
  }
}

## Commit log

2024-04-22 Add files
    First contents
    [LAMPU_EMERGENCY_v1.0.brd, LAMPU_EMERGENCY_v1.0.sch, LAMPU_EMERGENCY_v1.1.brd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]
2024-09-07 add smd 2 layers board
    [LAMPU_EMERGENCY_v1.3_all_module_smd.brd, LAMPU_EMERGENCY_v1.3_all_module_smd.sch]
2024-09-14 Split X and Y vibration sensors
    separate it, maybe someone use sensors have different type
    [LAMPU_EMERGENCY_v1.3_all_module_smd.brd, LAMPU_EMERGENCY_v1.3_all_module_smd.sch]
2024-10-23 change battery limit

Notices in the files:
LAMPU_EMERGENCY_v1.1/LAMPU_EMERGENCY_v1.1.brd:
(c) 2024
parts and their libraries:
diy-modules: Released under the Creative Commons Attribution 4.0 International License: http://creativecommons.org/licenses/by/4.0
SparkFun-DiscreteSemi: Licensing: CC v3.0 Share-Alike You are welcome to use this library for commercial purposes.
